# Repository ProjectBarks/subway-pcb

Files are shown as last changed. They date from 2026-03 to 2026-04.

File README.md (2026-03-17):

# NYC Subway PCB

Real-time NYC subway train tracker on a custom PCB with 478 WS2812B LEDs forming the subway map.

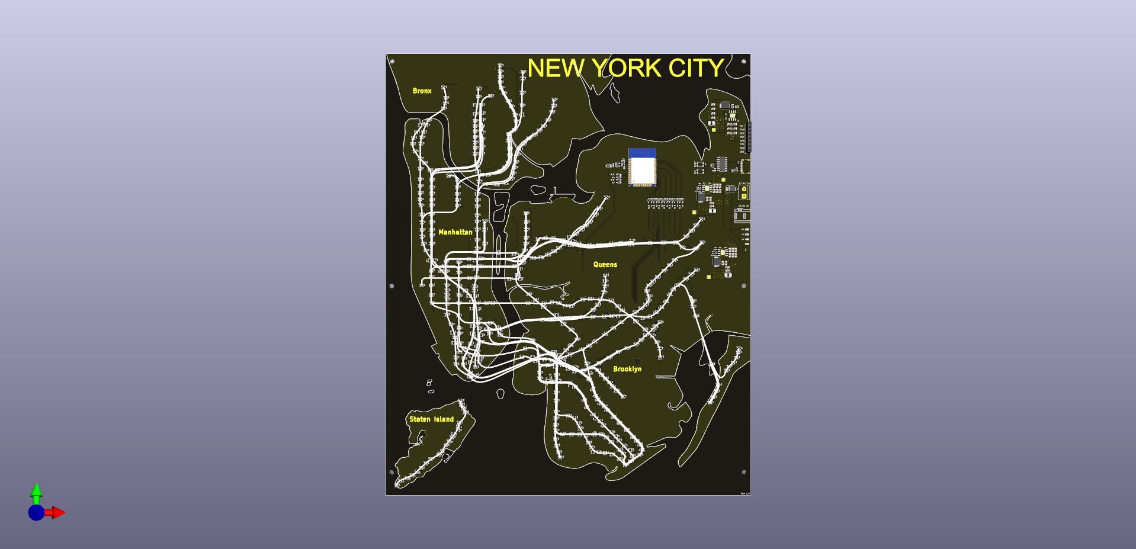
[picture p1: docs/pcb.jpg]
PCB Board


A Go server polls MTA's GTFS real-time feeds, renders train positions as pixel data, and streams it to an ESP32 over WiFi. Each LED lights up with the subway line's color when a train is at that station.

## Architecture

```
MTA GTFS-RT (9 feeds) → Go Server → protobuf → ESP32 → 478 LEDs
                              ↓
                     Web visualizer (:8080)
```

- **Server** polls MTA every 15s, maps trains to LED positions, serves pre-rendered pixel frames via protobuf
- **ESP32** connects to WiFi, fetches pixel data every second, drives 9 LED strips
- **Web UI** shows the same data overlaid on the PCB silkscreen (KiCad SVG)

## Quick Start

```bash
# Start the server (polls live MTA data, serves web UI + pixel API)
make server

# Flash production firmware to ESP32
make fw-flash

# Open web visualizer
open http://localhost:8080
```

## Project Structure

```
server/                    Go server
  cmd/subway-server/         Entry point
  internal/mta/              MTA feed polling + aggregation
  internal/api/              HTTP API + pixel rendering
  static/                    Web UI (board.js, app.js, leds.json, board.svg)
  led_map.json               Station → LED position mapping

firmware/                  ESP32 production firmware (PlatformIO + ESP-IDF)
  src/                       main.c, led_driver, subway_client
  proto/                     nanopb protobuf (PixelFrame)
  components/                External deps (esp_ghota, esp32-wifi-manager, led_strip)

proto/                     Shared protobuf schema (subway.proto)

pcb/                       KiCad hardware design files

tools/
  debug-firmware/            Arduino firmware for serial LED control
  led-debugger-ui/           Click-to-light web debugger (Python)
  led-mapping-ui/            LED position mapping tool (Python/Tkinter)
  serial-logger/             Resilient serial logger with auto-reconnect
```

## Make Targets

```
make help          Show all targets
make server        Build and start Go server
make fw-flash      Build and flash production firmware
make dbg-flash     Flash debug firmware (serial LED control)
make monitor       Start serial logger
make debugger      Start LED debugger web UI
make clean         Clean all build artifacts
```

## Hardware

- ESP32-WROOM-32 with CH340C USB-serial
- 478 WS2812B LEDs across 9 strips (GPIO 16-23, 25, 26)
- 12V barrel jack / battery terminal for LED power
- SN74LV1T34DBV level shifters (3.3V → 5V)

## Data Flow

1. Server fetches VehiclePosition from 9 MTA GTFS-RT feeds
2. Filters to STOPPED_AT trains only (actually at a station)
3. Maps station IDs to LED positions via `led_map.json`
4. Renders 478 RGB pixels with route-appropriate colors
5. Wraps in PixelFrame protobuf, serves at `GET /api/v1/pixels`
6. ESP32 polls every second, writes pixels directly to LED strips

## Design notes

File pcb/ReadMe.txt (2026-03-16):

Hello

Here are the projects files

The kicad project files contains the source files of your designs. you have to use Kicad software to open those files

gerber files are for manufacture the pcb.
pick and place files are useful if you use assembly service from the pcb manufacturer.

3d step file. this file is 3d model of you design. if this folder is empty then it means you have to ordered it.
The 3D design file is useful if you create a mechanical drawing with pcb.
For example if you design a enclouser. if you want to buy this let me know.

images and pdf folder contains images of pcb and schematic as pdf

BOM file is a excel file which contains the part list for your pcb

========================

For PCB manufacturing process I would like to recommend you PCBWay.com.
Here are some reasons I use their service.

1. Easy to use
2. They provide assembling service
3. They accept components from recognized stores such as mouser, digikey
4. They solder through hole components as well

I can guide you to place the order PCb using PCBWAY.COM

Additionally here is a referral link which will give you a discount
https://www.pcbway.com/setinvite.aspx?inviteid=325163

========================

here is ordering guide for PCBway.com, watch this video

https://drive.google.com/file/d/1q8oiihPp48wS0tmCgw_dWEVFPIduA3-2/view?usp=sharing

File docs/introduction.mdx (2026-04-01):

---
title: Introduction
description: Real-time NYC subway train tracker on a custom PCB with 478 WS2812B LEDs
---

NYC Subway PCB

# NYC Subway PCB

Real-time NYC subway train tracker on a custom PCB with 478 WS2812B LEDs forming the subway map.

A Go server polls MTA's GTFS real-time feeds, renders train positions as pixel data, and streams it to an ESP32 over WiFi. Each LED lights up with the subway line's color when a train is at that station.

## Architecture

```
MTA GTFS-RT (9 feeds) → Go Server → protobuf → ESP32 → 478 LEDs
                              ↓
                     Web visualizer (:8080)
```

- **Server** polls MTA every 15s, maps trains to LED positions, serves pre-rendered pixel frames via protobuf
- **ESP32** connects to WiFi, fetches pixel data every second, drives 9 LED strips
- **Web UI** shows the same data overlaid on the PCB silkscreen

## Quick Start

```bash
# Start the server (polls live MTA data, serves web UI + pixel API)
make backend/start

# Flash production firmware to ESP32
make firmware/flash

# Open web visualizer
open http://localhost:8080
```

## Hardware

- ESP32-WROOM-32 with CH340C USB-serial
- 478 WS2812B LEDs across 9 strips
- 12V barrel jack / battery terminal for LED power
- SN74LV1T34DBV level shifters (3.3V → 5V)

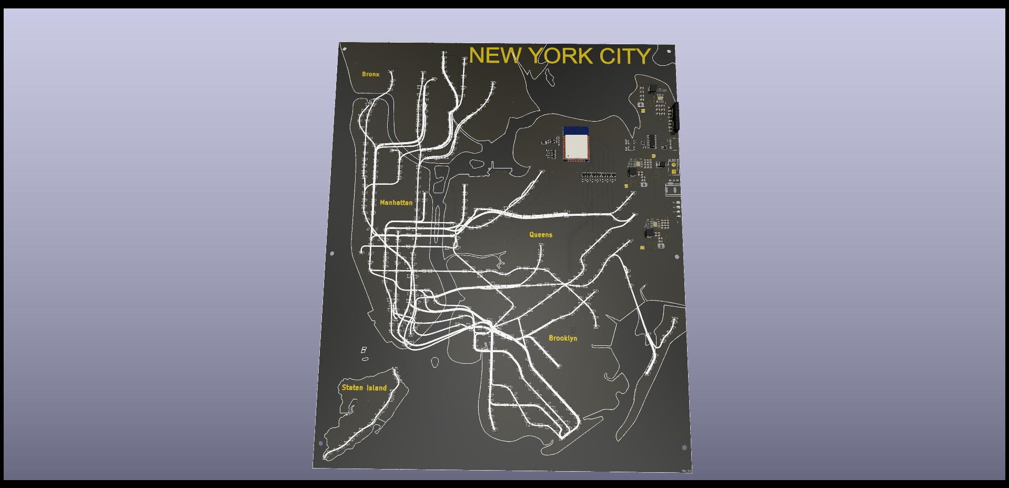
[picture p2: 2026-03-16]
pcb/images and pdf/design.jpg

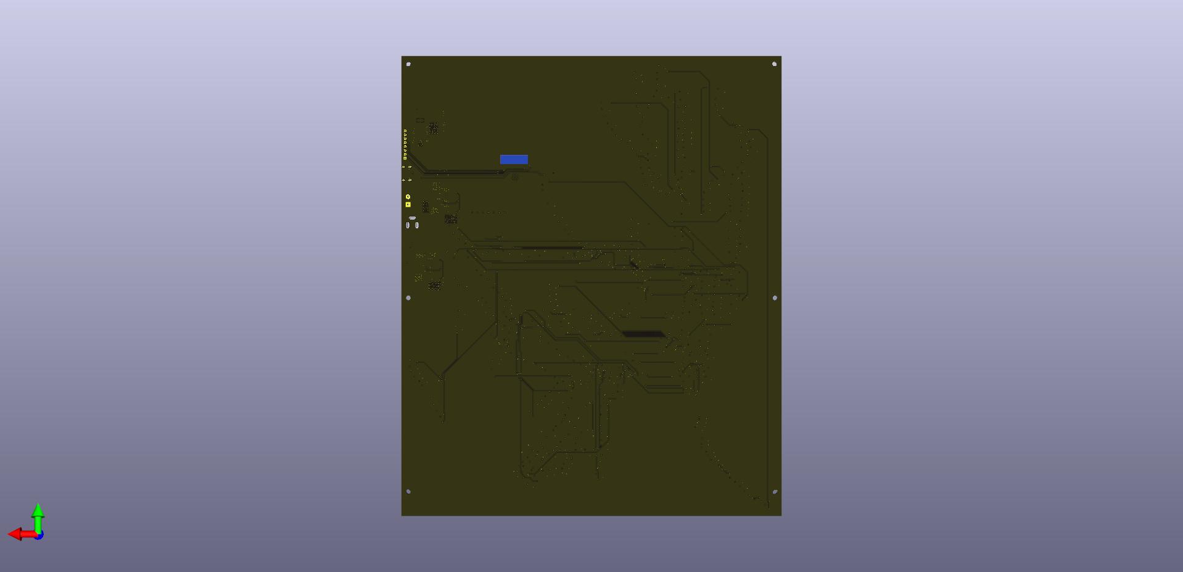
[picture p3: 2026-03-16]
pcb/images and pdf/bootm.jpg

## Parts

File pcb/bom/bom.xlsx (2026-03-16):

Designator | Comment | Footprint | JLCPCB Part # | MPN | Qty
C1 | 10uF | Capacitor_SMD:C_0603_1608Metric | C344022 | GRM188R61E106KA73D | 1
C2 | 0.1uF | Capacitor_SMD:C_0402_1005Metric | C77020 | GRM155R71H104KE14D | 1
C3 | 0.1uF | Capacitor_SMD:C_0402_1005Metric | C77020 | GRM155R71H104KE14D | 1
C4 | 10uF | Capacitor_SMD:C_0603_1608Metric | C344022 | GRM188R61E106KA73D | 1
C5 | 1uF | Capacitor_SMD:C_0603_1608Metric | C3011671 | GRT188R61H105ME13D | 1
C6 | 10uF | Capacitor_SMD:C_0603_1608Metric | C344022 | GRM188R61E106KA73D | 1
C7 | 10uF | Capacitor_SMD:C_0603_1608Metric | C344022 | GRM188R61E106KA73D | 1
C8 | 100u | CAPPM3528X210N | C597710 | TPSB107K006R0250 | 1
C9 | 10u 35v | Capacitor_SMD:C_0805_2012Metric | C361063 | GRM21BR6YA106ME43L | 1
C10 | 10u 35v | Capacitor_SMD:C_0805_2012Metric | C361063 | GRM21BR6YA106ME43L | 1
C11 | 10u 35v | Capacitor_SMD:C_0805_2012Metric | C361063 | GRM21BR6YA106ME43L | 1
C12 | 10u 35v | Capacitor_SMD:C_0805_2012Metric | C361063 | GRM21BR6YA106ME43L | 1
C13 | 0.1uF | Capacitor_SMD:C_0402_1005Metric | C77020 | GRM155R71H104KE14D | 1
C14 | nf | Capacitor_SMD:C_0402_1005Metric | dnp | dnp | 1
C15 | 10u 35v | Capacitor_SMD:C_0805_2012Metric | C361063 | GRM21BR6YA106ME43L | 1
C16 | 10u 35v | Capacitor_SMD:C_0805_2012Metric | C361063 | GRM21BR6YA106ME43L | 1
C17 | 10u 35v | Capacitor_SMD:C_0805_2012Metric | C361063 | GRM21BR6YA106ME43L | 1
C18 | 10u 35v | Capacitor_SMD:C_0805_2012Metric | C361063 | GRM21BR6YA106ME43L | 1
C19 | 10u 35v | Capacitor_SMD:C_0805_2012Metric | C361063 | GRM21BR6YA106ME43L | 1
C20 | 10u 35v | Capacitor_SMD:C_0805_2012Metric | C361063 | GRM21BR6YA106ME43L | 1
C21 | 0.1uF | Capacitor_SMD:C_0402_1005Metric | C77020 | GRM155R71H104KE14D | 1
C22 | nf | Capacitor_SMD:C_0402_1005Metric | dnp | dnp | 1
C23 | 1.2nF | Capacitor_SMD:C_0402_1005Metric | C295919 | 0402B122J500CT | 1
C24 | 100u | CAPPM3528X210N | C597710 | TPSB107K006R0250 | 1
C25 | 10u 35v | Capacitor_SMD:C_0805_2012Metric | C361063 | GRM21BR6YA106ME43L | 1
C26 | 10u 35v | Capacitor_SMD:C_0805_2012Metric | C361063 | GRM21BR6YA106ME43L | 1
C27 | 10u 35v | Capacitor_SMD:C_0805_2012Metric | C361063 | GRM21BR6YA106ME43L | 1
C28 | 10u 35v | Capacitor_SMD:C_0805_2012Metric | C361063 | GRM21BR6YA106ME43L | 1
C29 | 0.1uF | Capacitor_SMD:C_0402_1005Metric | C77020 | GRM155R71H104KE14D | 1
C30 | nf | Capacitor_SMD:C_0402_1005Metric | dnp | dnp | 1
C31 | 10u 35v | Capacitor_SMD:C_0805_2012Metric | C361063 | GRM21BR6YA106ME43L | 1
C32 | 10u 35v | Capacitor_SMD:C_0805_2012Metric | C361063 | GRM21BR6YA106ME43L | 1
C33 | 10u 35v | Capacitor_SMD:C_0805_2012Metric | C361063 | GRM21BR6YA106ME43L | 1
C34 | 10u 35v | Capacitor_SMD:C_0805_2012Metric | C361063 | GRM21BR6YA106ME43L | 1
C35 | 10u 35v | Capacitor_SMD:C_0805_2012Metric | C361063 | GRM21BR6YA106ME43L | 1
C36 | 10u 35v | Capacitor_SMD:C_0805_2012Metric | C361063 | GRM21BR6YA106ME43L | 1
C37 | 0.1uF | Capacitor_SMD:C_0402_1005Metric | C77020 | GRM155R71H104KE14D | 1
C38 | nf | Capacitor_SMD:C_0402_1005Metric | dnp | dnp | 1
C39 | 1.2nF | Capacitor_SMD:C_0402_1005Metric | C295919 | 0402B122J500CT | 1
C40 | 100u | CAPPM3528X210N | C597710 | TPSB107K006R0250 | 1
C41 | 10u 35v | Capacitor_SMD:C_0805_2012Metric | C361063 | GRM21BR6YA106ME43L | 1
C42 | 10u 35v | Capacitor_SMD:C_0805_2012Metric | C361063 | GRM21BR6YA106ME43L | 1
C43 | 10u 35v | Capacitor_SMD:C_0805_2012Metric | C361063 | GRM21BR6YA106ME43L | 1
C44 | 10u 35v | Capacitor_SMD:C_0805_2012Metric | C361063 | GRM21BR6YA106ME43L | 1
C45 | 0.1uF | Capacitor_SMD:C_0402_1005Metric | C77020 | GRM155R71H104KE14D | 1
C46 | nf | Capacitor_SMD:C_0402_1005Metric | dnp | dnp | 1
C47 | 10u 35v | Capacitor_SMD:C_0805_2012Metric | C361063 | GRM21BR6YA106ME43L | 1
C48 | 10u 35v | Capacitor_SMD:C_0805_2012Metric | C361063 | GRM21BR6YA106ME43L | 1
C49 | 10u 35v | Capacitor_SMD:C_0805_2012Metric | C361063 | GRM21BR6YA106ME43L | 1
C50 | 10u 35v | Capacitor_SMD:C_0805_2012Metric | C361063 | GRM21BR6YA106ME43L | 1
C51 | 10u 35v | Capacitor_SMD:C_0805_2012Metric | C361063 | GRM21BR6YA106ME43L | 1
C52 | 10u 35v | Capacitor_SMD:C_0805_2012Metric | C361063 | GRM21BR6YA106ME43L | 1
C53 | 0.1uF | Capacitor_SMD:C_0402_1005Metric | C77020 | GRM155R71H104KE14D | 1
C54 | nf | Capacitor_SMD:C_0402_1005Metric | dnp | dnp | 1
C55 | 1.2nF | Capacitor_SMD:C_0402_1005Metric | C295919 | 0402B122J500CT | 1
C56 | 0.1uF | Capacitor_SMD:C_0402_1005Metric | C77020 | GRM155R71H104KE14D | 1
C57 | 0.1uF | Capacitor_SMD:C_0402_1005Metric | C77020 | GRM155R71H104KE14D | 1
C58 | 0.1uF | Capacitor_SMD:C_0402_1005Metric | C77020 | GRM155R71H104KE14D | 1
C59 | 0.1uF | Capacitor_SMD:C_0402_1005Metric | C77020 | GRM155R71H104KE14D | 1
C60 | 0.1uF | Capacitor_SMD:C_0402_1005Metric | C77020 | GRM155R71H104KE14D | 1
C61 | 0.1uF | Capacitor_SMD:C_0402_1005Metric | C77020 | GRM155R71H104KE14D | 1
C62 | 0.1uF | Capacitor_SMD:C_0402_1005Metric | C77020 | GRM155R71H104KE14D | 1
C63 | 0.1uF | Capacitor_SMD:C_0402_1005Metric | C77020 | GRM155R71H104KE14D | 1
C64 | 0.1uF | Capacitor_SMD:C_0402_1005Metric | C77020 | GRM155R71H104KE14D | 1
C65 | 0.1uF | Capacitor_SMD:C_0402_1005Metric | C77020 | GRM155R71H104KE14D | 1
C66 | 0.1uF | Capacitor_SMD:C_0402_1005Metric | C77020 | GRM155R71H104KE14D | 1
C67 | 0.1uF | Capacitor_SMD:C_0402_1005Metric | C77020 | GRM155R71H104KE14D | 1
C68 | 0.1uF | Capacitor_SMD:C_0402_1005Metric | C77020 | GRM155R71H104KE14D | 1
C69 | 0.1uF | Capacitor_SMD:C_0402_1005Metric | C77020 | GRM155R71H104KE14D | 1
C70 | 0.1uF | Capacitor_SMD:C_0402_1005Metric | C77020 | GRM155R71H104KE14D | 1
C71 | 0.1uF | Capacitor_SMD:C_0402_1005Metric | C77020 | GRM155R71H104KE14D | 1
C72 | 0.1uF | Capacitor_SMD:C_0402_1005Metric | C77020 | GRM155R71H104KE14D | 1
C73 | 0.1uF | Capacitor_SMD:C_0402_1005Metric | C77020 | GRM155R71H104KE14D | 1
C74 | 0.1uF | Capacitor_SMD:C_0402_1005Metric | C77020 | GRM155R71H104KE14D | 1
C75 | 0.1uF | Capacitor_SMD:C_0402_1005Metric | C77020 | GRM155R71H104KE14D | 1
C76 | 0.1uF | Capacitor_SMD:C_0402_1005Metric | C77020 | GRM155R71H104KE14D | 1
C77 | 0.1uF | Capacitor_SMD:C_0402_1005Metric | C77020 | GRM155R71H104KE14D | 1
C78 | 0.1uF | Capacitor_SMD:C_0402_1005Metric | C77020 | GRM155R71H104KE14D | 1
C79 | 0.1uF | Capacitor_SMD:C_0402_1005Metric | C77020 | GRM155R71H104KE14D | 1
C80 | 0.1uF | Capacitor_SMD:C_0402_1005Metric | C77020 | GRM155R71H104KE14D | 1
C81 | 0.1uF | Capacitor_SMD:C_0402_1005Metric | C77020 | GRM155R71H104KE14D | 1
C82 | 0.1uF | Capacitor_SMD:C_0402_1005Metric | C77020 | GRM155R71H104KE14D | 1
C83 | 0.1uF | Capacitor_SMD:C_0402_1005Metric | C77020 | GRM155R71H104KE14D | 1
C84 | 0.1uF | Capacitor_SMD:C_0402_1005Metric | C77020 | GRM155R71H104KE14D | 1
C85 | 0.1uF | Capacitor_SMD:C_0402_1005Metric | C77020 | GRM155R71H104KE14D | 1
C86 | 0.1uF | Capacitor_SMD:C_0402_1005Metric | C77020 | GRM155R71H104KE14D | 1
C87 | 0.1uF | Capacitor_SMD:C_0402_1005Metric | C77020 | GRM155R71H104KE14D | 1
C88 | 0.1uF | Capacitor_SMD:C_0402_1005Metric | C77020 | GRM155R71H104KE14D | 1
C89 | 0.1uF | Capacitor_SMD:C_0402_1005Metric | C77020 | GRM155R71H104KE14D | 1
C90 | 0.1uF | Capacitor_SMD:C_0402_1005Metric | C77020 | GRM155R71H104KE14D | 1
C91 | 0.1uF | Capacitor_SMD:C_0402_1005Metric | C77020 | GRM155R71H104KE14D | 1
C92 | 0.1uF | Capacitor_SMD:C_0402_1005Metric | C77020 | GRM155R71H104KE14D | 1
C93 | 0.1uF | Capacitor_SMD:C_0402_1005Metric | C77020 | GRM155R71H104KE14D | 1
C94 | 0.1uF | Capacitor_SMD:C_0402_1005Metric | C77020 | GRM155R71H104KE14D | 1
C95 | 0.1uF | Capacitor_SMD:C_0402_1005Metric | C77020 | GRM155R71H104KE14D | 1
C96 | 0.1uF | Capacitor_SMD:C_0402_1005Metric | C77020 | GRM155R71H104KE14D | 1
C97 | 0.1uF | Capacitor_SMD:C_0402_1005Metric | C77020 | GRM155R71H104KE14D | 1
C98 | 0.1uF | Capacitor_SMD:C_0402_1005Metric | C77020 | GRM155R71H104KE14D | 1
C99 | 0.1uF | Capacitor_SMD:C_0402_1005Metric | C77020 | GRM155R71H104KE14D | 1
C100 | 0.1uF | Capacitor_SMD:C_0402_1005Metric | C77020 | GRM155R71H104KE14D | 1
C101 | 0.1uF | Capacitor_SMD:C_0402_1005Metric | C77020 | GRM155R71H104KE14D | 1
C102 | 0.1uF | Capacitor_SMD:C_0402_1005Metric | C77020 | GRM155R71H104KE14D | 1
C103 | 0.1uF | Capacitor_SMD:C_0402_1005Metric | C77020 | GRM155R71H104KE14D | 1
C104 | 0.1uF | Capacitor_SMD:C_0402_1005Metric | C77020 | GRM155R71H104KE14D | 1
C105 | 0.1uF | Capacitor_SMD:C_0402_1005Metric | C77020 | GRM155R71H104KE14D | 1
C106 | 0.1uF | Capacitor_SMD:C_0402_1005Metric | C77020 | GRM155R71H104KE14D | 1
C107 | 0.1uF | Capacitor_SMD:C_0402_1005Metric | C77020 | GRM155R71H104KE14D | 1
C108 | 0.1uF | Capacitor_SMD:C_0402_1005Metric | C77020 | GRM155R71H104KE14D | 1
C109 | 0.1uF | Capacitor_SMD:C_0402_1005Metric | C77020 | GRM155R71H104KE14D | 1
C110 | 0.1uF | Capacitor_SMD:C_0402_1005Metric | C77020 | GRM155R71H104KE14D | 1
C111 | 0.1uF | Capacitor_SMD:C_0402_1005Metric | C77020 | GRM155R71H104KE14D | 1
C112 | 0.1uF | Capacitor_SMD:C_0402_1005Metric | C77020 | GRM155R71H104KE14D | 1
C113 | 0.1uF | Capacitor_SMD:C_0402_1005Metric | C77020 | GRM155R71H104KE14D | 1
C114 | 0.1uF | Capacitor_SMD:C_0402_1005Metric | C77020 | GRM155R71H104KE14D | 1
C115 | 0.1uF | Capacitor_SMD:C_0402_1005Metric | C77020 | GRM155R71H104KE14D | 1
C116 | 0.1uF | Capacitor_SMD:C_0402_1005Metric | C77020 | GRM155R71H104KE14D | 1
C117 | 0.1uF | Capacitor_SMD:C_0402_1005Metric | C77020 | GRM155R71H104KE14D | 1
C118 | 0.1uF | Capacitor_SMD:C_0402_1005Metric | C77020 | GRM155R71H104KE14D | 1
C119 | 0.1uF | Capacitor_SMD:C_0402_1005Metric | C77020 | GRM155R71H104KE14D | 1
C120 | 0.1uF | Capacitor_SMD:C_0402_1005Metric | C77020 | GRM155R71H104KE14D | 1
C121 | 0.1uF | Capacitor_SMD:C_0402_1005Metric | C77020 | GRM155R71H104KE14D | 1
C122 | 0.1uF | Capacitor_SMD:C_0402_1005Metric | C77020 | GRM155R71H104KE14D | 1
C123 | 0.1uF | Capacitor_SMD:C_0402_1005Metric | C77020 | GRM155R71H104KE14D | 1
C124 | 0.1uF | Capacitor_SMD:C_0402_1005Metric | C77020 | GRM155R71H104KE14D | 1
C125 | 0.1uF | Capacitor_SMD:C_0402_1005Metric | C77020 | GRM155R71H104KE14D | 1
C126 | 0.1uF | Capacitor_SMD:C_0402_1005Metric | C77020 | GRM155R71H104KE14D | 1
C127 | 0.1uF | Capacitor_SMD:C_0402_1005Metric | C77020 | GRM155R71H104KE14D | 1
C128 | 0.1uF | Capacitor_SMD:C_0402_1005Metric | C77020 | GRM155R71H104KE14D | 1
C129 | 0.1uF | Capacitor_SMD:C_0402_1005Metric | C77020 | GRM155R71H104KE14D | 1
C130 | 0.1uF | Capacitor_SMD:C_0402_1005Metric | C77020 | GRM155R71H104KE14D | 1
C131 | 0.1uF | Capacitor_SMD:C_0402_1005Metric | C77020 | GRM155R71H104KE14D | 1
C132 | 0.1uF | Capacitor_SMD:C_0402_1005Metric | C77020 | GRM155R71H104KE14D | 1
C133 | 0.1uF | Capacitor_SMD:C_0402_1005Metric | C77020 | GRM155R71H104KE14D | 1
C134 | 0.1uF | Capacitor_SMD:C_0402_1005Metric | C77020 | GRM155R71H104KE14D | 1
C135 | 0.1uF | Capacitor_SMD:C_0402_1005Metric | C77020 | GRM155R71H104KE14D | 1
C136 | 0.1uF | Capacitor_SMD:C_0402_1005Metric | C77020 | GRM155R71H104KE14D | 1
C137 | 0.1uF | Capacitor_SMD:C_0402_1005Metric | C77020 | GRM155R71H104KE14D | 1
C138 | 0.1uF | Capacitor_SMD:C_0402_1005Metric | C77020 | GRM155R71H104KE14D | 1
C139 | 0.1uF | Capacitor_SMD:C_0402_1005Metric | C77020 | GRM155R71H104KE14D | 1
C140 | 0.1uF | Capacitor_SMD:C_0402_1005Metric | C77020 | GRM155R71H104KE14D | 1
C141 | 0.1uF | Capacitor_SMD:C_0402_1005Metric | C77020 | GRM155R71H104KE14D | 1
C142 | 0.1uF | Capacitor_SMD:C_0402_1005Metric | C77020 | GRM155R71H104KE14D | 1
C143 | 0.1uF | Capacitor_SMD:C_0402_1005Metric | C77020 | GRM155R71H104KE14D | 1
C144 | 0.1uF | Capacitor_SMD:C_0402_1005Metric | C77020 | GRM155R71H104KE14D | 1
C145 | 0.1uF | Capacitor_SMD:C_0402_1005Metric | C77020 | GRM155R71H104KE14D | 1
C146 | 0.1uF | Capacitor_SMD:C_0402_1005Metric | C77020 | GRM155R71H104KE14D | 1
C147 | 0.1uF | Capacitor_SMD:C_0402_1005Metric | C77020 | GRM155R71H104KE14D | 1
C148 | 0.1uF | Capacitor_SMD:C_0402_1005Metric | C77020 | GRM155R71H104KE14D | 1
C149 | 0.1uF | Capacitor_SMD:C_0402_1005Metric | C77020 | GRM155R71H104KE14D | 1
C150 | 0.1uF | Capacitor_SMD:C_0402_1005Metric | C77020 | GRM155R71H104KE14D | 1
C151 | 0.1uF | Capacitor_SMD:C_0402_1005Metric | C77020 | GRM155R71H104KE14D | 1
C152 | 0.1uF | Capacitor_SMD:C_0402_1005Metric | C77020 | GRM155R71H104KE14D | 1
C153 | 0.1uF | Capacitor_SMD:C_0402_1005Metric | C77020 | GRM155R71H104KE14D | 1
C154 | 0.1uF | Capacitor_SMD:C_0402_1005Metric | C77020 | GRM155R71H104KE14D | 1
C155 | 0.1uF | Capacitor_SMD:C_0402_1005Metric | C77020 | GRM155R71H104KE14D | 1
C156 | 0.1uF | Capacitor_SMD:C_0402_1005Metric | C77020 | GRM155R71H104KE14D | 1
C157 | 0.1uF | Capacitor_SMD:C_0402_1005Metric | C77020 | GRM155R71H104KE14D | 1
C158 | 0.1uF | Capacitor_SMD:C_0402_1005Metric | C77020 | GRM155R71H104KE14D | 1
C159 | 0.1uF | Capacitor_SMD:C_0402_1005Metric | C77020 | GRM155R71H104KE14D | 1
C160 | 0.1uF | Capacitor_SMD:C_0402_1005Metric | C77020 | GRM155R71H104KE14D | 1
C161 | 0.1uF | Capacitor_SMD:C_0402_1005Metric | C77020 | GRM155R71H104KE14D | 1
C162 | 0.1uF | Capacitor_SMD:C_0402_1005Metric | C77020 | GRM155R71H104KE14D | 1
C163 | 0.1uF | Capacitor_SMD:C_0402_1005Metric | C77020 | GRM155R71H104KE14D | 1
C164 | 0.1uF | Capacitor_SMD:C_0402_1005Metric | C77020 | GRM155R71H104KE14D | 1
C165 | 0.1uF | Capacitor_SMD:C_0402_1005Metric | C77020 | GRM155R71H104KE14D | 1
C166 | 0.1uF | Capacitor_SMD:C_0402_1005Metric | C77020 | GRM155R71H104KE14D | 1
C167 | 0.1uF | Capacitor_SMD:C_0402_1005Metric | C77020 | GRM155R71H104KE14D | 1
C168 | 0.1uF | Capacitor_SMD:C_0402_1005Metric | C77020 | GRM155R71H104KE14D | 1
C169 | 0.1uF | Capacitor_SMD:C_0402_1005Metric | C77020 | GRM155R71H104KE14D | 1
C170 | 0.1uF | Capacitor_SMD:C_0402_1005Metric | C77020 | GRM155R71H104KE14D | 1
C171 | 0.1uF | Capacitor_SMD:C_0402_1005Metric | C77020 | GRM155R71H104KE14D | 1
C172 | 0.1uF | Capacitor_SMD:C_0402_1005Metric | C77020 | GRM155R71H104KE14D | 1
C173 | 0.1uF | Capacitor_SMD:C_0402_1005Metric | C77020 | GRM155R71H104KE14D | 1
C174 | 0.1uF | Capacitor_SMD:C_0402_1005Metric | C77020 | GRM155R71H104KE14D | 1
C175 | 0.1uF | Capacitor_SMD:C_0402_1005Metric | C77020 | GRM155R71H104KE14D | 1
C176 | 0.1uF | Capacitor_SMD:C_0402_1005Metric | C77020 | GRM155R71H104KE14D | 1
C177 | 0.1uF | Capacitor_SMD:C_0402_1005Metric | C77020 | GRM155R71H104KE14D | 1
C178 | 0.1uF | Capacitor_SMD:C_0402_1005Metric | C77020 | GRM155R71H104KE14D | 1
C179 | 0.1uF | Capacitor_SMD:C_0402_1005Metric | C77020 | GRM155R71H104KE14D | 1
C180 | 0.1uF | Capacitor_SMD:C_0402_1005Metric | C77020 | GRM155R71H104KE14D | 1
C181 | 0.1uF | Capacitor_SMD:C_0402_1005Metric | C77020 | GRM155R71H104KE14D | 1
C182 | 0.1uF | Capacitor_SMD:C_0402_1005Metric | C77020 | GRM155R71H104KE14D | 1
C183 | 0.1uF | Capacitor_SMD:C_0402_1005Metric | C77020 | GRM155R71H104KE14D | 1
C184 | 0.1uF | Capacitor_SMD:C_0402_1005Metric | C77020 | GRM155R71H104KE14D | 1
C185 | 0.1uF | Capacitor_SMD:C_0402_1005Metric | C77020 | GRM155R71H104KE14D | 1
C186 | 0.1uF | Capacitor_SMD:C_0402_1005Metric | C77020 | GRM155R71H104KE14D | 1
C187 | 0.1uF | Capacitor_SMD:C_0402_1005Metric | C77020 | GRM155R71H104KE14D | 1
C188 | 0.1uF | Capacitor_SMD:C_0402_1005Metric | C77020 | GRM155R71H104KE14D | 1
C189 | 0.1uF | Capacitor_SMD:C_0402_1005Metric | C77020 | GRM155R71H104KE14D | 1
C190 | 0.1uF | Capacitor_SMD:C_0402_1005Metric | C77020 | GRM155R71H104KE14D | 1
C191 | 0.1uF | Capacitor_SMD:C_0402_1005Metric | C77020 | GRM155R71H104KE14D | 1
C192 | 0.1uF | Capacitor_SMD:C_0402_1005Metric | C77020 | GRM155R71H104KE14D | 1
C193 | 0.1uF | Capacitor_SMD:C_0402_1005Metric | C77020 | GRM155R71H104KE14D | 1
C194 | 0.1uF | Capacitor_SMD:C_0402_1005Metric | C77020 | GRM155R71H104KE14D | 1
C195 | 0.1uF | Capacitor_SMD:C_0402_1005Metric | C77020 | GRM155R71H104KE14D | 1
C196 | 0.1uF | Capacitor_SMD:C_0402_1005Metric | C77020 | GRM155R71H104KE14D | 1
C197 | 0.1uF | Capacitor_SMD:C_0402_1005Metric | C77020 | GRM155R71H104KE14D | 1
C198 | 0.1uF | Capacitor_SMD:C_0402_1005Metric | C77020 | GRM155R71H104KE14D | 1
C199 | 0.1uF | Capacitor_SMD:C_0402_1005Metric | C77020 | GRM155R71H104KE14D | 1
C200 | 0.1uF | Capacitor_SMD:C_0402_1005Metric | C77020 | GRM155R71H104KE14D | 1
C201 | 0.1uF | Capacitor_SMD:C_0402_1005Metric | C77020 | GRM155R71H104KE14D | 1
C202 | 0.1uF | Capacitor_SMD:C_0402_1005Metric | C77020 | GRM155R71H104KE14D | 1
C203 | 0.1uF | Capacitor_SMD:C_0402_1005Metric | C77020 | GRM155R71H104KE14D | 1
C204 | 0.1uF | Capacitor_SMD:C_0402_1005Metric | C77020 | GRM155R71H104KE14D | 1
C205 | 0.1uF | Capacitor_SMD:C_0402_1005Metric | C77020 | GRM155R71H104KE14D | 1
C206 | 0.1uF | Capacitor_SMD:C_0402_1005Metric | C77020 | GRM155R71H104KE14D | 1
C207 | 0.1uF | Capacitor_SMD:C_0402_1005Metric | C77020 | GRM155R71H104KE14D | 1
C208 | 0.1uF | Capacitor_SMD:C_0402_1005Metric | C77020 | GRM155R71H104KE14D | 1
C209 | 0.1uF | Capacitor_SMD:C_0402_1005Metric | C77020 | GRM155R71H104KE14D | 1
C210 | 0.1uF | Capacitor_SMD:C_0402_1005Metric | C77020 | GRM155R71H104KE14D | 1
C211 | 0.1uF | Capacitor_SMD:C_0402_1005Metric | C77020 | GRM155R71H104KE14D | 1
C212 | 0.1uF | Capacitor_SMD:C_0402_1005Metric | C77020 | GRM155R71H104KE14D | 1
C213 | 0.1uF | Capacitor_SMD:C_0402_1005Metric | C77020 | GRM155R71H104KE14D | 1
C214 | 0.1uF | Capacitor_SMD:C_0402_1005Metric | C77020 | GRM155R71H104KE14D | 1
C215 | 0.1uF | Capacitor_SMD:C_0402_1005Metric | C77020 | GRM155R71H104KE14D | 1
C216 | 0.1uF | Capacitor_SMD:C_0402_1005Metric | C77020 | GRM155R71H104KE14D | 1
C217 | 0.1uF | Capacitor_SMD:C_0402_1005Metric | C77020 | GRM155R71H104KE14D | 1
C218 | 0.1uF | Capacitor_SMD:C_0402_1005Metric | C77020 | GRM155R71H104KE14D | 1
C219 | 0.1uF | Capacitor_SMD:C_0402_1005Metric | C77020 | GRM155R71H104KE14D | 1
C220 | 0.1uF | Capacitor_SMD:C_0402_1005Metric | C77020 | GRM155R71H104KE14D | 1
C221 | 0.1uF | Capacitor_SMD:C_0402_1005Metric | C77020 | GRM155R71H104KE14D | 1
C222 | 0.1uF | Capacitor_SMD:C_0402_1005Metric | C77020 | GRM155R71H104KE14D | 1
C223 | 0.1uF | Capacitor_SMD:C_0402_1005Metric | C77020 | GRM155R71H104KE14D | 1
C224 | 0.1uF | Capacitor_SMD:C_0402_1005Metric | C77020 | GRM155R71H104KE14D | 1
C225 | 0.1uF | Capacitor_SMD:C_0402_1005Metric | C77020 | GRM155R71H104KE14D | 1
C226 | 0.1uF | Capacitor_SMD:C_0402_1005Metric | C77020 | GRM155R71H104KE14D | 1
C227 | 0.1uF | Capacitor_SMD:C_0402_1005Metric | C77020 | GRM155R71H104KE14D | 1
C228 | 0.1uF | Capacitor_SMD:C_0402_1005Metric | C77020 | GRM155R71H104KE14D | 1
C229 | 0.1uF | Capacitor_SMD:C_0402_1005Metric | C77020 | GRM155R71H104KE14D | 1
C230 | 0.1uF | Capacitor_SMD:C_0402_1005Metric | C77020 | GRM155R71H104KE14D | 1
C231 | 0.1uF | Capacitor_SMD:C_0402_1005Metric | C77020 | GRM155R71H104KE14D | 1
C232 | 0.1uF | Capacitor_SMD:C_0402_1005Metric | C77020 | GRM155R71H104KE14D | 1
C233 | 0.1uF | Capacitor_SMD:C_0402_1005Metric | C77020 | GRM155R71H104KE14D | 1
C234 | 0.1uF | Capacitor_SMD:C_0402_1005Metric | C77020 | GRM155R71H104KE14D | 1
C235 | 0.1uF | Capacitor_SMD:C_0402_1005Metric | C77020 | GRM155R71H104KE14D | 1
C236 | 0.1uF | Capacitor_SMD:C_0402_1005Metric | C77020 | GRM155R71H104KE14D | 1
C237 | 0.1uF | Capacitor_SMD:C_0402_1005Metric | C77020 | GRM155R71H104KE14D | 1
C238 | 0.1uF | Capacitor_SMD:C_0402_1005Metric | C77020 | GRM155R71H104KE14D | 1
C239 | 0.1uF | Capacitor_SMD:C_0402_1005Metric | C77020 | GRM155R71H104KE14D | 1
C240 | 0.1uF | Capacitor_SMD:C_0402_1005Metric | C77020 | GRM155R71H104KE14D | 1
C241 | 0.1uF | Capacitor_SMD:C_0402_1005Metric | C77020 | GRM155R71H104KE14D | 1
C242 | 0.1uF | Capacitor_SMD:C_0402_1005Metric | C77020 | GRM155R71H104KE14D | 1
C243 | 0.1uF | Capacitor_SMD:C_0402_1005Metric | C77020 | GRM155R71H104KE14D | 1
C244 | 0.1uF | Capacitor_SMD:C_0402_1005Metric | C77020 | GRM155R71H104KE14D | 1
C245 | 0.1uF | Capacitor_SMD:C_0402_1005Metric | C77020 | GRM155R71H104KE14D | 1
C246 | 0.1uF | Capacitor_SMD:C_0402_1005Metric | C77020 | GRM155R71H104KE14D | 1
C247 | 0.1uF | Capacitor_SMD:C_0402_1005Metric | C77020 | GRM155R71H104KE14D | 1
C248 | 0.1uF | Capacitor_SMD:C_0402_1005Metric | C77020 | GRM155R71H104KE14D | 1
C249 | 0.1uF | Capacitor_SMD:C_0402_1005Metric | C77020 | GRM155R71H104KE14D | 1
C250 | 0.1uF | Capacitor_SMD:C_0402_1005Metric | C77020 | GRM155R71H104KE14D | 1
C251 | 0.1uF | Capacitor_SMD:C_0402_1005Metric | C77020 | GRM155R71H104KE14D | 1
C252 | 0.1uF | Capacitor_SMD:C_0402_1005Metric | C77020 | GRM155R71H104KE14D | 1
C253 | 0.1uF | Capacitor_SMD:C_0402_1005Metric | C77020 | GRM155R71H104KE14D | 1
C254 | 0.1uF | Capacitor_SMD:C_0402_1005Metric | C77020 | GRM155R71H104KE14D | 1
C255 | 0.1uF | Capacitor_SMD:C_0402_1005Metric | C77020 | GRM155R71H104KE14D | 1
C256 | 0.1uF | Capacitor_SMD:C_0402_1005Metric | C77020 | GRM155R71H104KE14D | 1
C257 | 0.1uF | Capacitor_SMD:C_0402_1005Metric | C77020 | GRM155R71H104KE14D | 1
C258 | 0.1uF | Capacitor_SMD:C_0402_1005Metric | C77020 | GRM155R71H104KE14D | 1
C259 | 0.1uF | Capacitor_SMD:C_0402_1005Metric | C77020 | GRM155R71H104KE14D | 1
C260 | 0.1uF | Capacitor_SMD:C_0402_1005Metric | C77020 | GRM155R71H104KE14D | 1
C261 | 0.1uF | Capacitor_SMD:C_0402_1005Metric | C77020 | GRM155R71H104KE14D | 1
C262 | 0.1uF | Capacitor_SMD:C_0402_1005Metric | C77020 | GRM155R71H104KE14D | 1
C263 | 0.1uF | Capacitor_SMD:C_0402_1005Metric | C77020 | GRM155R71H104KE14D | 1
C264 | 0.1uF | Capacitor_SMD:C_0402_1005Metric | C77020 | GRM155R71H104KE14D | 1
C265 | 0.1uF | Capacitor_SMD:C_0402_1005Metric | C77020 | GRM155R71H104KE14D | 1
C266 | 0.1uF | Capacitor_SMD:C_0402_1005Metric | C77020 | GRM155R71H104KE14D | 1
C267 | 0.1uF | Capacitor_SMD:C_0402_1005Metric | C77020 | GRM155R71H104KE14D | 1
C268 | 0.1uF | Capacitor_SMD:C_0402_1005Metric | C77020 | GRM155R71H104KE14D | 1
C269 | 0.1uF | Capacitor_SMD:C_0402_1005Metric | C77020 | GRM155R71H104KE14D | 1
C270 | 0.1uF | Capacitor_SMD:C_0402_1005Metric | C77020 | GRM155R71H104KE14D | 1
C271 | 0.1uF | Capacitor_SMD:C_0402_1005Metric | C77020 | GRM155R71H104KE14D | 1
C272 | 0.1uF | Capacitor_SMD:C_0402_1005Metric | C77020 | GRM155R71H104KE14D | 1
C273 | 0.1uF | Capacitor_SMD:C_0402_1005Metric | C77020 | GRM155R71H104KE14D | 1
C274 | 0.1uF | Capacitor_SMD:C_0402_1005Metric | C77020 | GRM155R71H104KE14D | 1
C275 | 0.1uF | Capacitor_SMD:C_0402_1005Metric | C77020 | GRM155R71H104KE14D | 1
C276 | 0.1uF | Capacitor_SMD:C_0402_1005Metric | C77020 | GRM155R71H104KE14D | 1
C277 | 0.1uF | Capacitor_SMD:C_0402_1005Metric | C77020 | GRM155R71H104KE14D | 1
C278 | 0.1uF | Capacitor_SMD:C_0402_1005Metric | C77020 | GRM155R71H104KE14D | 1
C279 | 0.1uF | Capacitor_SMD:C_0402_1005Metric | C77020 | GRM155R71H104KE14D | 1
C280 | 0.1uF | Capacitor_SMD:C_0402_1005Metric | C77020 | GRM155R71H104KE14D | 1
C281 | 0.1uF | Capacitor_SMD:C_0402_1005Metric | C77020 | GRM155R71H104KE14D | 1
C282 | 0.1uF | Capacitor_SMD:C_0402_1005Metric | C77020 | GRM155R71H104KE14D | 1
C283 | 0.1uF | Capacitor_SMD:C_0402_1005Metric | C77020 | GRM155R71H104KE14D | 1
C284 | 0.1uF | Capacitor_SMD:C_0402_1005Metric | C77020 | GRM155R71H104KE14D | 1
C285 | 0.1uF | Capacitor_SMD:C_0402_1005Metric | C77020 | GRM155R71H104KE14D | 1
C286 | 0.1uF | Capacitor_SMD:C_0402_1005Metric | C77020 | GRM155R71H104KE14D | 1
C287 | 0.1uF | Capacitor_SMD:C_0402_1005Metric | C77020 | GRM155R71H104KE14D | 1
C288 | 0.1uF | Capacitor_SMD:C_0402_1005Metric | C77020 | GRM155R71H104KE14D | 1
C289 | 0.1uF | Capacitor_SMD:C_0402_1005Metric | C77020 | GRM155R71H104KE14D | 1
C290 | 0.1uF | Capacitor_SMD:C_0402_1005Metric | C77020 | GRM155R71H104KE14D | 1
C291 | 0.1uF | Capacitor_SMD:C_0402_1005Metric | C77020 | GRM155R71H104KE14D | 1
C292 | 0.1uF | Capacitor_SMD:C_0402_1005Metric | C77020 | GRM155R71H104KE14D | 1
C293 | 0.1uF | Capacitor_SMD:C_0402_1005Metric | C77020 | GRM155R71H104KE14D | 1
C294 | 0.1uF | Capacitor_SMD:C_0402_1005Metric | C77020 | GRM155R71H104KE14D | 1
C295 | 0.1uF | Capacitor_SMD:C_0402_1005Metric | C77020 | GRM155R71H104KE14D | 1
C296 | 0.1uF | Capacitor_SMD:C_0402_1005Metric | C77020 | GRM155R71H104KE14D | 1
C297 | 0.1uF | Capacitor_SMD:C_0402_1005Metric | C77020 | GRM155R71H104KE14D | 1
C298 | 0.1uF | Capacitor_SMD:C_0402_1005Metric | C77020 | GRM155R71H104KE14D | 1
C299 | 0.1uF | Capacitor_SMD:C_0402_1005Metric | C77020 | GRM155R71H104KE14D | 1
C300 | 0.1uF | Capacitor_SMD:C_0402_1005Metric | C77020 | GRM155R71H104KE14D | 1
C301 | 0.1uF | Capacitor_SMD:C_0402_1005Metric | C77020 | GRM155R71H104KE14D | 1
C302 | 0.1uF | Capacitor_SMD:C_0402_1005Metric | C77020 | GRM155R71H104KE14D | 1
C303 | 0.1uF | Capacitor_SMD:C_0402_1005Metric | C77020 | GRM155R71H104KE14D | 1
C304 | 0.1uF | Capacitor_SMD:C_0402_1005Metric | C77020 | GRM155R71H104KE14D | 1
C305 | 0.1uF | Capacitor_SMD:C_0402_1005Metric | C77020 | GRM155R71H104KE14D | 1
C306 | 0.1uF | Capacitor_SMD:C_0402_1005Metric | C77020 | GRM155R71H104KE14D | 1
C307 | 0.1uF | Capacitor_SMD:C_0402_1005Metric | C77020 | GRM155R71H104KE14D | 1
C308 | 0.1uF | Capacitor_SMD:C_0402_1005Metric | C77020 | GRM155R71H104KE14D | 1
C309 | 0.1uF | Capacitor_SMD:C_0402_1005Metric | C77020 | GRM155R71H104KE14D | 1
C310 | 0.1uF | Capacitor_SMD:C_0402_1005Metric | C77020 | GRM155R71H104KE14D | 1
C311 | 0.1uF | Capacitor_SMD:C_0402_1005Metric | C77020 | GRM155R71H104KE14D | 1
C312 | 0.1uF | Capacitor_SMD:C_0402_1005Metric | C77020 | GRM155R71H104KE14D | 1
C313 | 0.1uF | Capacitor_SMD:C_0402_1005Metric | C77020 | GRM155R71H104KE14D | 1
C314 | 0.1uF | Capacitor_SMD:C_0402_1005Metric | C77020 | GRM155R71H104KE14D | 1
C315 | 0.1uF | Capacitor_SMD:C_0402_1005Metric | C77020 | GRM155R71H104KE14D | 1
C316 | 0.1uF | Capacitor_SMD:C_0402_1005Metric | C77020 | GRM155R71H104KE14D | 1
C317 | 0.1uF | Capacitor_SMD:C_0402_1005Metric | C77020 | GRM155R71H104KE14D | 1
C318 | 0.1uF | Capacitor_SMD:C_0402_1005Metric | C77020 | GRM155R71H104KE14D | 1
C319 | 0.1uF | Capacitor_SMD:C_0402_1005Metric | C77020 | GRM155R71H104KE14D | 1
C320 | 0.1uF | Capacitor_SMD:C_0402_1005Metric | C77020 | GRM155R71H104KE14D | 1
C321 | 0.1uF | Capacitor_SMD:C_0402_1005Metric | C77020 | GRM155R71H104KE14D | 1
C322 | 0.1uF | Capacitor_SMD:C_0402_1005Metric | C77020 | GRM155R71H104KE14D | 1
C323 | 0.1uF | Capacitor_SMD:C_0402_1005Metric | C77020 | GRM155R71H104KE14D | 1
C324 | 0.1uF | Capacitor_SMD:C_0402_1005Metric | C77020 | GRM155R71H104KE14D | 1
C325 | 0.1uF | Capacitor_SMD:C_0402_1005Metric | C77020 | GRM155R71H104KE14D | 1
C326 | 0.1uF | Capacitor_SMD:C_0402_1005Metric | C77020 | GRM155R71H104KE14D | 1
C327 | 0.1uF | Capacitor_SMD:C_0402_1005Metric | C77020 | GRM155R71H104KE14D | 1
C328 | 0.1uF | Capacitor_SMD:C_0402_1005Metric | C77020 | GRM155R71H104KE14D | 1
C329 | 0.1uF | Capacitor_SMD:C_0402_1005Metric | C77020 | GRM155R71H104KE14D | 1
C330 | 0.1uF | Capacitor_SMD:C_0402_1005Metric | C77020 | GRM155R71H104KE14D | 1
C331 | 0.1uF | Capacitor_SMD:C_0402_1005Metric | C77020 | GRM155R71H104KE14D | 1
C332 | 0.1uF | Capacitor_SMD:C_0402_1005Metric | C77020 | GRM155R71H104KE14D | 1
C333 | 0.1uF | Capacitor_SMD:C_0402_1005Metric | C77020 | GRM155R71H104KE14D | 1
C334 | 0.1uF | Capacitor_SMD:C_0402_1005Metric | C77020 | GRM155R71H104KE14D | 1
C335 | 0.1uF | Capacitor_SMD:C_0402_1005Metric | C77020 | GRM155R71H104KE14D | 1
C336 | 0.1uF | Capacitor_SMD:C_0402_1005Metric | C77020 | GRM155R71H104KE14D | 1
C337 | 0.1uF | Capacitor_SMD:C_0402_1005Metric | C77020 | GRM155R71H104KE14D | 1
C338 | 0.1uF | Capacitor_SMD:C_0402_1005Metric | C77020 | GRM155R71H104KE14D | 1
C339 | 0.1uF | Capacitor_SMD:C_0402_1005Metric | C77020 | GRM155R71H104KE14D | 1
C340 | 0.1uF | Capacitor_SMD:C_0402_1005Metric | C77020 | GRM155R71H104KE14D | 1
C341 | 0.1uF | Capacitor_SMD:C_0402_1005Metric | C77020 | GRM155R71H104KE14D | 1
C342 | 0.1uF | Capacitor_SMD:C_0402_1005Metric | C77020 | GRM155R71H104KE14D | 1
C343 | 0.1uF | Capacitor_SMD:C_0402_1005Metric | C77020 | GRM155R71H104KE14D | 1
C344 | 0.1uF | Capacitor_SMD:C_0402_1005Metric | C77020 | GRM155R71H104KE14D | 1
C345 | 0.1uF | Capacitor_SMD:C_0402_1005Metric | C77020 | GRM155R71H104KE14D | 1
C346 | 0.1uF | Capacitor_SMD:C_0402_1005Metric | C77020 | GRM155R71H104KE14D | 1
C347 | 0.1uF | Capacitor_SMD:C_0402_1005Metric | C77020 | GRM155R71H104KE14D | 1
C348 | 0.1uF | Capacitor_SMD:C_0402_1005Metric | C77020 | GRM155R71H104KE14D | 1
C349 | 0.1uF | Capacitor_SMD:C_0402_1005Metric | C77020 | GRM155R71H104KE14D | 1
C350 | 0.1uF | Capacitor_SMD:C_0402_1005Metric | C77020 | GRM155R71H104KE14D | 1
C351 | 0.1uF | Capacitor_SMD:C_0402_1005Metric | C77020 | GRM155R71H104KE14D | 1
C352 | 0.1uF | Capacitor_SMD:C_0402_1005Metric | C77020 | GRM155R71H104KE14D | 1
C353 | 0.1uF | Capacitor_SMD:C_0402_1005Metric | C77020 | GRM155R71H104KE14D | 1
C354 | 0.1uF | Capacitor_SMD:C_0402_1005Metric | C77020 | GRM155R71H104KE14D | 1
C355 | 0.1uF | Capacitor_SMD:C_0402_1005Metric | C77020 | GRM155R71H104KE14D | 1
C356 | 0.1uF | Capacitor_SMD:C_0402_1005Metric | C77020 | GRM155R71H104KE14D | 1
C357 | 0.1uF | Capacitor_SMD:C_0402_1005Metric | C77020 | GRM155R71H104KE14D | 1
C358 | 0.1uF | Capacitor_SMD:C_0402_1005Metric | C77020 | GRM155R71H104KE14D | 1
C359 | 0.1uF | Capacitor_SMD:C_0402_1005Metric | C77020 | GRM155R71H104KE14D | 1
C360 | 0.1uF | Capacitor_SMD:C_0402_1005Metric | C77020 | GRM155R71H104KE14D | 1
C361 | 0.1uF | Capacitor_SMD:C_0402_1005Metric | C77020 | GRM155R71H104KE14D | 1
C362 | 0.1uF | Capacitor_SMD:C_0402_1005Metric | C77020 | GRM155R71H104KE14D | 1
C363 | 0.1uF | Capacitor_SMD:C_0402_1005Metric | C77020 | GRM155R71H104KE14D | 1
C364 | 0.1uF | Capacitor_SMD:C_0402_1005Metric | C77020 | GRM155R71H104KE14D | 1
C365 | 0.1uF | Capacitor_SMD:C_0402_1005Metric | C77020 | GRM155R71H104KE14D | 1
C366 | 0.1uF | Capacitor_SMD:C_0402_1005Metric | C77020 | GRM155R71H104KE14D | 1
C367 | 0.1uF | Capacitor_SMD:C_0402_1005Metric | C77020 | GRM155R71H104KE14D | 1
C368 | 0.1uF | Capacitor_SMD:C_0402_1005Metric | C77020 | GRM155R71H104KE14D | 1
C369 | 0.1uF | Capacitor_SMD:C_0402_1005Metric | C77020 | GRM155R71H104KE14D | 1
C370 | 0.1uF | Capacitor_SMD:C_0402_1005Metric | C77020 | GRM155R71H104KE14D | 1
C371 | 0.1uF | Capacitor_SMD:C_0402_1005Metric | C77020 | GRM155R71H104KE14D | 1
C372 | 0.1uF | Capacitor_SMD:C_0402_1005Metric | C77020 | GRM155R71H104KE14D | 1
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

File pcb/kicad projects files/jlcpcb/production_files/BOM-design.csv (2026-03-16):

Comment | Designator | Footprint | LCSC
SN74LV1T34DBV | U10,U11,U12,U13,U14,U15,U7,U8,U9 | SOT-23-5 | C100024
1k | R14,R9 | R_0402_1005Metric | C100195
5.1k | R1,R2 | R_0402_1005Metric | C105872
220R | R22,R23,R24,R25,R26,R27,R28,R29,R30 | R_0603_1608Metric | C107696
12K 1% | R13,R18,R8 | R_0402_1005Metric | C114760
2.2K 1% | R11,R16,R21 | R_0402_1005Metric | C114762
MBR230S1F-7 | D1,D2 | D_SOD-123F | C151335
AP2127K-3.3 | U3 | SOT-23-5 | C156285
1uF | C5 | C_0603_1608Metric | C15849
10R | R12,R17,R7 | R_0402_1005Metric | C176108
AP64501SP-13 | U4,U5,U6 | SOIC-8-1EP_3.9x4.9mm_P1.27mm_EP2.95x4.9mm_Mask2.71x3.4mm_ThermalVias | C2071517
1.2nF | C23,C39,C55 | C_0402_1005Metric | C295919
USB_C_Receptacle_USB2.0 | J2 | USB_C_Receptacle_G-Switch_GT-USB-7010ASV | C2988369
12V IN | J4 | CONN-TH_DC-005-2.5A-2.0 | C319099
10uF | C1,C4,C6,C7 | C_0603_1608Metric | C344022
10u 35v | C10,C11,C12,C15,C16,C17,C18,C19,C20,C25,C26,C27,C28,C31,C32,C33,C34,C35,C36,C41,C42,C43,C44,C47,C48,C49,C50,C51,C52,C9 | C_0805_2012Metric | C361063
ESP32-WROOM-32 | U2 | ESP32-WROOM-32 | C529582
ETQ-P3M3R3KVP | L1,L2,L3 | ETQ-P3M_KVP | C542316
100u | C24,C40,C8 | CP_EIA-3528-21_Kemet-B | C597710
10k | R4,R5,R6 | R_0402_1005Metric | C60490
100k | R3 | R_0402_1005Metric | C60491
UMH3N | Q1 | SOT-363_SC-70-6 | C62892
D_Schottky | D5 | D_SMB | C698845
BATTERY | J3 | TerminalBlock_bornier-2_P5.08mm | C709041
SW_Push | SW1,SW2 | SW_Push_1P1T_NO_CK_KMR2 | C72443
CH340C | U1 | SOIC-16_3.9x9.9mm_P1.27mm | C7464026
0.1uF | C100,C101,C102,C103,C104,C105,C106,C107,C108,C109,C110,C111,C112,C113,C114,C115,C116,C117,C118,C119,C120,C121,C122,C123,C124,C125,C126,C127,C128,C129,C13,C130,C131,C132,C133,C134,C135,C136,C137,C138,C139,C140,C141,C142,C143,C144,C145,C146,C147,C148,C149,C150,C151,C152,C153,C154,C155,C156,C157,C158,C159,C160,C161,C162,C163,C164,C165,C166,C167,C168,C169,C170,C171,C172,C173,C174,C175,C176,C177,C178,C179,C180,C181,C182,C183,C184,C185,C186,C187,C188,C189,C190,C191,C192,C193,C194,C195,C196,C197,C198,C199,C2,C200,C201,C202,C203,C204,C205,C206,C207,C208,C209,C21,C210,C211,C212,C213,C214,C215,C216,C217,C218,C219,C220,C221,C222,C223,C224,C225,C226,C227,C228,C229,C230,C231,C232,C233,C234,C235,C236,C237,C238,C239,C240,C241,C242,C243,C244,C245,C246,C247,C248,C249,C250,C251,C252,C253,C254,C255,C256,C257,C258,C259,C260,C261,C262,C263,C264,C265,C266,C267,C268,C269,C270,C271,C272,C273,C274,C275,C276,C277,C278,C279,C280,C281,C282,C283,C284,C285,C286,C287,C288,C289,C29,C290,C291,C292,C293,C294,C295,C296,C297,C298,C299,C3,C300,C301,C302,C303,C304,C305,C306,C307,C308,C309,C310,C311,C312,C313,C314,C315,C316,C317,C318,C319,C320,C321,C322,C323,C324,C325,C326,C327,C328,C329,C330,C331,C332,C333,C334,C335,C336,C337,C338,C339,C340,C341,C342,C343,C344,C345,C346,C347,C348,C349,C350,C351,C352,C353,C354,C355,C356,C357,C358,C359,C360,C361,C362,C363,C364,C365,C366,C367,C368,C369,C37,C370,C371,C372,C373,C374,C375,C376,C377,C378,C379,C380,C381,C382,C383,C384,C385,C386,C387,C388,C389,C390,C391,C392,C393,C394,C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 | C_0402_1005Metric | C77020
20K 1% | R10,R15,R20 | R_0402_1005Metric | C93942
WS2812B | D10,D100,D101,D102,D103,D104,D105,D106,D107,D108,D109,D11,D110,D111,D112,D113,D114,D115,D116,D117,D118,D119,D12,D120,D121,D122,D123,D124,D125,D126,D127,D128,D129,D13,D130,D131,D132,D133,D134,D135,D136,D137,D138,D139,D14,D140,D141,D142,D143,D144,D145,D146,D147,D148,D149,D15,D150,D151,D152,D153,D154,D155,D156,D157,D158,D159,D16,D160,D161,D162,D163,D164,D165,D166,D167,D168,D169,D17,D170,D171,D172,D173,D174,D175,D176,D177,D178,D179,D18,D180,D181,D182,D183,D184,D185,D186,D187,D188,D189,D19,D190,D191,D192,D193,D194,D195,D196,D197,D198,D199,D20,D200,D201,D202,D203,D204,D205,D206,D207,D208,D209,D21,D210,D211,D212,D213,D214,D215,D216,D217,D218,D219,D22,D220,D221,D222,D223,D224,D225,D226,D227,D228,D229,D23,D230,D231,D232,D233,D234,D235,D236,D237,D238,D239,D24,D240,D241,D242,D243,D244,D245,D246,D247,D248,D249,D25,D250,D251,D252,D253,D254,D255,D256,D257,D258,D259,D26,D260,D261,D262,D263,D264,D265,D266,D267,D268,D269,D27,D270,D271,D272,D273,D274,D275,D276,D277,D278,D279,D28,D280,D281,D282,D283,D284,D285,D286,D287,D288,D289,D29,D290,D291,D292,D293,D294,D295,D296,D297,D298,D299,D30,D300,D301,D302,D303,D304,D305,D306,D307,D308,D309,D31,D310,D311,D312,D313,D314,D315,D316,D317,D318,D319,D32,D320,D321,D322,D323,D324,D325,D326,D327,D328,D329,D33,D330,D331,D332,D333,D334,D335,D336,D337,D338,D339,D34,D340,D341,D342,D343,D344,D345,D346,D347,D348,D349,D35,D350,D351,D352,D353,D354,D355,D356,D357,D358,D359,D36,D360,D361,D362,D363,D364,D365,D366,D367,D368,D369,D37,D370,D371,D372,D373,D374,D375,D376,D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 | LED_WS2812B-2020_PLCC4_2.0x2.0mm | C965555
RED | D3,D4,D6,D7 | LED_0603_1608Metric | C965799
nf | C22 | C_0402_1005Metric
MountingHole | H6 | MountingHole_3.2mm_M3
TestPoint | TP4 | TestPoint_Pad_2.0x2.0mm
nf | C46 | C_0402_1005Metric
TestPoint | TP1 | TestPoint_Pad_2.0x2.0mm
nf | C54 | C_0402_1005Metric
nf | C30 | C_0402_1005Metric
MountingHole | H1 | MountingHole_3.2mm_M3
Conn_01x08 | J1 | PinSocket_1x08_P2.54mm_Vertical
MountingHole | H3 | MountingHole_3.2mm_M3
nf | C38 | C_0402_1005Metric
TestPoint | TP3 | TestPoint_Pad_2.0x2.0mm
TestPoint | TP2 | TestPoint_Pad_2.0x2.0mm
nf | C14 | C_0402_1005Metric
MountingHole | H2 | MountingHole_3.2mm_M3
MountingHole | H4 | MountingHole_3.2mm_M3
MountingHole | H5 | MountingHole_3.2mm_M3

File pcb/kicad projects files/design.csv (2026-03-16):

Source: | G:\My Drive\fiverr 2023\projectbarks FO81D43F66982 led battery charging usb\kicad projects files\design.kicad_sch
Date: | 11/12/2023 09:17:35
Tool: | Eeschema 7.0.9
Generator: | C:\Program Files\KiCad\7.0\bin\scripting\plugins/bom_csv_grouped_by_value_with_fp.py
Component Count: | 1091
Ref | Qnty | Value | Cmp name | Footprint | Description | Vendor | DNP
C1, C4, C6, C7 | 4 | 10uF | C | Capacitor_SMD:C_0603_1608Metric | Unpolarized capacitor
C2, C3, C13, C21, C29, C37, C45, C53, C56, C57, C58, C59, C60, C61, C62, C63, C64, C65, C66, C67, C68, C69, C70, C71, C72, C73, C74, C75, C76, C77, C78, C79, C80, C81, C82, C83, C84, C85, C86, C87, C88, C89, C90, C91, C92, C93, C94, C95, C96, C97, C98, C99, C100, C101, C102, C103, C104, C105, C106, C107, C108, C109, C110, C111, C112, C113, C114, C115, C116, C117, C118, C119, C120, C121, C122, C123, C124, C125, C126, C127, C128, C129, C130, C131, C132, C133, C134, C135, C136, C137, C138, C139, C140, C141, C142, C143, C144, C145, C146, C147, C148, C149, C150, C151, C152, C153, C154, C155, C156, C157, C158, C159, C160, C161, C162, C163, C164, C165, C166, C167, C168, C169, C170, C171, C172, C173, C174, C175, C176, C177, C178, C179, C180, C181, C182, C183, C184, C185, C186, C187, C188, C189, C190, C191, C192, C193, C194, C195, C196, C197, C198, C199, C200, C201, C202, C203, C204, C205, C206, C207, C208, C209, C210, C211, C212, C213, C214, C215, C216, C217, C218, C219, C220, C221, C222, C223, C224, C225, C226, C227, C228, C229, C230, C231, C232, C233, C234, C235, C236, C237, C238, C239, C240, C241, C242, C243, C244, C245, C246, C247, C248, C249, C250, C251, C252, C253, C254, C255, C256, C257, C258, C259, C260, C261, C262, C263, C264, C265, C266, C267, C268, C269, C270, C271, C272, C273, C274, C275, C276, C277, C278, C279, C280, C281, C282, C283, C284, C285, C286, C287, C288, C289, C290, C291, C292, C293, C294, C295, C296, C297, C298, C299, C300, C301, C302, C303, C304, C305, C306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 | 495 | 0.1uF | C | Capacitor_SMD:C_0402_1005Metric | Unpolarized capacitor
C5 | 1 | 1uF | C | Capacitor_SMD:C_0603_1608Metric | Unpolarized capacitor
C8, C24, C40 | 3 | 100u | TCJB107M006R0070E | CAPPM3528X210N | Conductive Polymer Solid Electrolytic Chip Capacitors
C9, C10, C11, C12, C15, C16, C17, C18, C19, C20, C25, C26, C27, C28, C31, C32, C33, C34, C35, C36, C41, C42, C43, C44, C47, C48, C49, C50, C51, C52 | 30 | 10u 35v | C | Capacitor_SMD:C_0805_2012Metric | Unpolarized capacitor
C14, C22, C30, C38, C46, C54 | 6 | nf | C | Capacitor_SMD:C_0402_1005Metric | Unpolarized capacitor
C23, C39, C55 | 3 | 1.2nF | C | Capacitor_SMD:C_0402_1005Metric | Unpolarized capacitor
D1, D2 | 2 | MBR230S1F-7 | D_Schottky | Diode_SMD:D_SOD-123F | Schottky diode
D3, D4, D6, D7 | 4 | RED | LED | LED_SMD:LED_0603_1608Metric | Light emitting diode
D5 | 1 | D_Schottky | D_Schottky | Diode_SMD:D_SMB | Schottky diode
D9, D10, D11, D12, D13, D14, D15, D16, D17, D18, D19, D20, D21, D22, D23, D24, D25, D26, D27, D28, D29, D30, D31, D32, D33, D34, D35, D36, D37, D38, D39, D40, D41, D42, D43, D44, D45, D46, D47, D48, D49, D50, D51, D52, D53, D54, D55, D56, D57, D58, D59, D60, D61, D62, D63, D64, D65, D66, D67, D68, D69, D70, D71, D72, D73, D74, D75, D76, D77, D78, D79, D80, D81, D82, D83, D84, D85, D86, D87, D88, D89, D90, D91, D92, D93, D94, D95, D96, D97, D98, D99, D100, D101, D102, D103, D104, D105, D106, D107, D108, D109, D110, D111, D112, D113, D114, D115, D116, D117, D118, D119, D120, D121, D122, D123, D124, D125, D126, D127, D128, D129, D130, D131, D132, D133, D134, D135, D136, D137, D138, D139, D140, D141, D142, D143, D144, D145, D146, D147, D148, D149, D150, D151, D152, D153, D154, D155, D156, D157, D158, D159, D160, D161, D162, D163, D164, D165, D166, D167, D168, D169, D170, D171, D172, D173, D174, D175, D176, D177, D178, D179, D180, D181, D182, D183, D184, D185, D186, D187, D188, D189, D190, D191, D192, D193, D194, D195, D196, D197, D198, D199, D200, D201, D202, D203, D204, D205, D206, D207, D208, D209, D210, D211, D212, D213, D214, D215, D216, D217, D218, D219, D220, D221, D222, D223, D224, D225, D226, D227, D228, D229, D230, D231, D232, D233, D234, D235, D236, D237, D238, D239, D240, D241, D242, D243, D244, D245, D246, D247, D248, D249, D250, D251, D252, D253, D254, D255, D256, D257, D258, D259, D260, D261, D262, D263, D264, D265, D266, D267, D268, D269, D270, D271, D272, D273, 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 | 478 | WS2812B | WS2812B-2020 | LED_SMD:LED_WS2812B-2020_PLCC4_2.0x2.0mm | RGB LED with integrated controller
H1, H2, H3, H4, H5, H6 | 6 | MountingHole | MountingHole | MountingHole:MountingHole_3.2mm_M3 | Mounting Hole without connection
J1 | 1 | Conn_01x08 | Conn_01x08 | Connector_PinSocket_2.54mm:PinSocket_1x08_P2.54mm_Vertical | Generic connector, single row, 01x08, script generated (kicad-library-utils/schlib/autogen/connector/)
J2 | 1 | USB_C_Receptacle_USB2.0 | USB_C_Receptacle_USB2.0 | Connector_USB:USB_C_Receptacle_G-Switch_GT-USB-7010ASV | USB 2.0-only Type-C Receptacle connector
J3 | 1 | BATTERY | Conn_01x02 | TerminalBlock:TerminalBlock_bornier-2_P5.08mm | Generic connector, single row, 01x02, script generated (kicad-library-utils/schlib/autogen/connector/)
J4 | 1 | 12V IN | Barrel_Jack_Switch | Library:CONN-TH_DC-005-2.5A-2.0 | DC Barrel Jack with an internal switch
L1, L2, L3 | 3 | ETQ-P3M3R3KVP | INDUCTOR | Library:ETQ-P3M_KVP | Inductor symbol for simulation only
Q1 | 1 | UMH3N | UMH3N | Package_TO_SOT_SMD:SOT-363_SC-70-6 | 0.1A Ic, 50V Vce, Dual NPN Input Resistor Transistors, SOT-363
R1, R2 | 2 | 5.1k | R | Resistor_SMD:R_0402_1005Metric | Resistor
R3 | 1 | 100k | R | Resistor_SMD:R_0402_1005Metric | Resistor
R4, R5, R6 | 3 | 10k | R | Resistor_SMD:R_0402_1005Metric | Resistor
R7, R12, R17 | 3 | 10R | R | Resistor_SMD:R_0402_1005Metric | Resistor
R8, R13, R18 | 3 | 12K 1% | R | Resistor_SMD:R_0402_1005Metric | Resistor
R9, R14 | 2 | 1k | R | Resistor_SMD:R_0402_1005Metric | Resistor
R10, R15, R20 | 3 | 20K 1% | R | Resistor_SMD:R_0402_1005Metric | Resistor
R11, R16, R21 | 3 | 2.2K 1% | R | Resistor_SMD:R_0402_1005Metric | Resistor
R22, R23, R24, R25, R26, R27, R28, R29, R30 | 9 | 220R | R | Resistor_SMD:R_0603_1608Metric | Resistor
SW1, SW2 | 2 | SW_Push | SW_Push | Button_Switch_SMD:SW_Push_1P1T_NO_CK_KMR2 | Push button switch, generic, two pins
TP1, TP2, TP3, TP4 | 4 | TestPoint | TestPoint | TestPoint:TestPoint_Pad_2.0x2.0mm | test point
U1 | 1 | CH340C | CH340C | Package_SO:SOIC-16_3.9x9.9mm_P1.27mm | USB serial converter, UART, SOIC-16
U2 | 1 | ESP32-WROOM-32 | ESP32-WROOM-32 | Library:ESP32-WROOM-32 | RF Module, ESP32-D0WDQ6 SoC, Wi-Fi 802.11b/g/n, Bluetooth, BLE, 32-bit, 2.7-3.6V, onboard antenna, SMD
U3 | 1 | AP2127K-3.3 | AP2127K-3.3 | Package_TO_SOT_SMD:SOT-23-5 | 300mA low dropout linear regulator, shutdown pin, 2.5V-6V input voltage, 3.3V fixed positive output, SOT-23-5
U4, U5, U6 | 3 | AP64501SP-13 | AP64351 | Library:SOIC-8-1EP_3.9x4.9mm_P1.27mm_EP2.95x4.9mm_Mask2.71x3.4mm_ThermalVias
U7, U8, U9, U10, U11, U12, U13, U14, U15 | 9 | SN74LV1T34DBV | SN74LV1T34DBV | Package_TO_SOT_SMD:SOT-23-5 | Single Power Supply, Single Buffer GATE, CMOS Logic, Level Shifter, SOT-23-5

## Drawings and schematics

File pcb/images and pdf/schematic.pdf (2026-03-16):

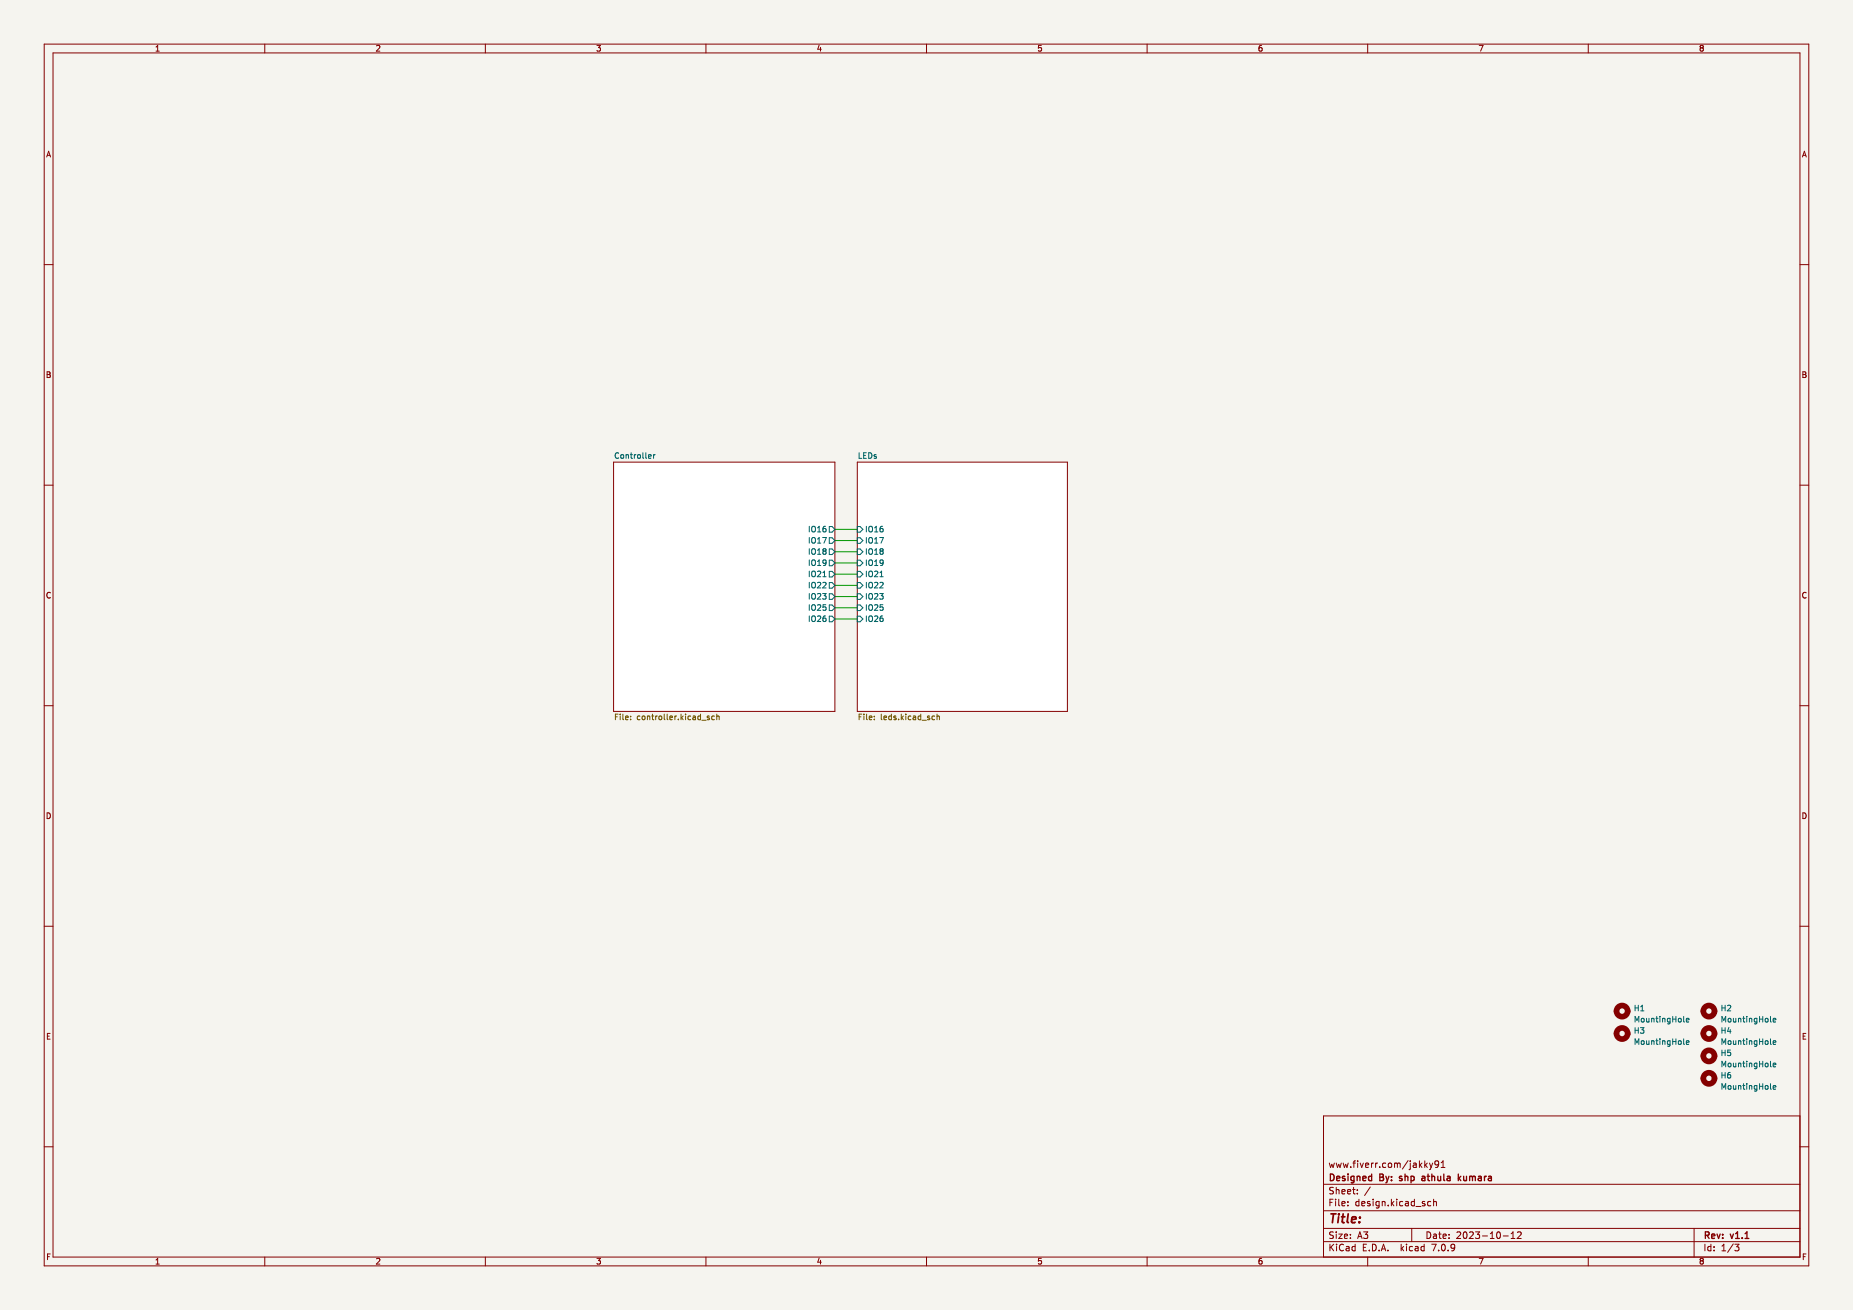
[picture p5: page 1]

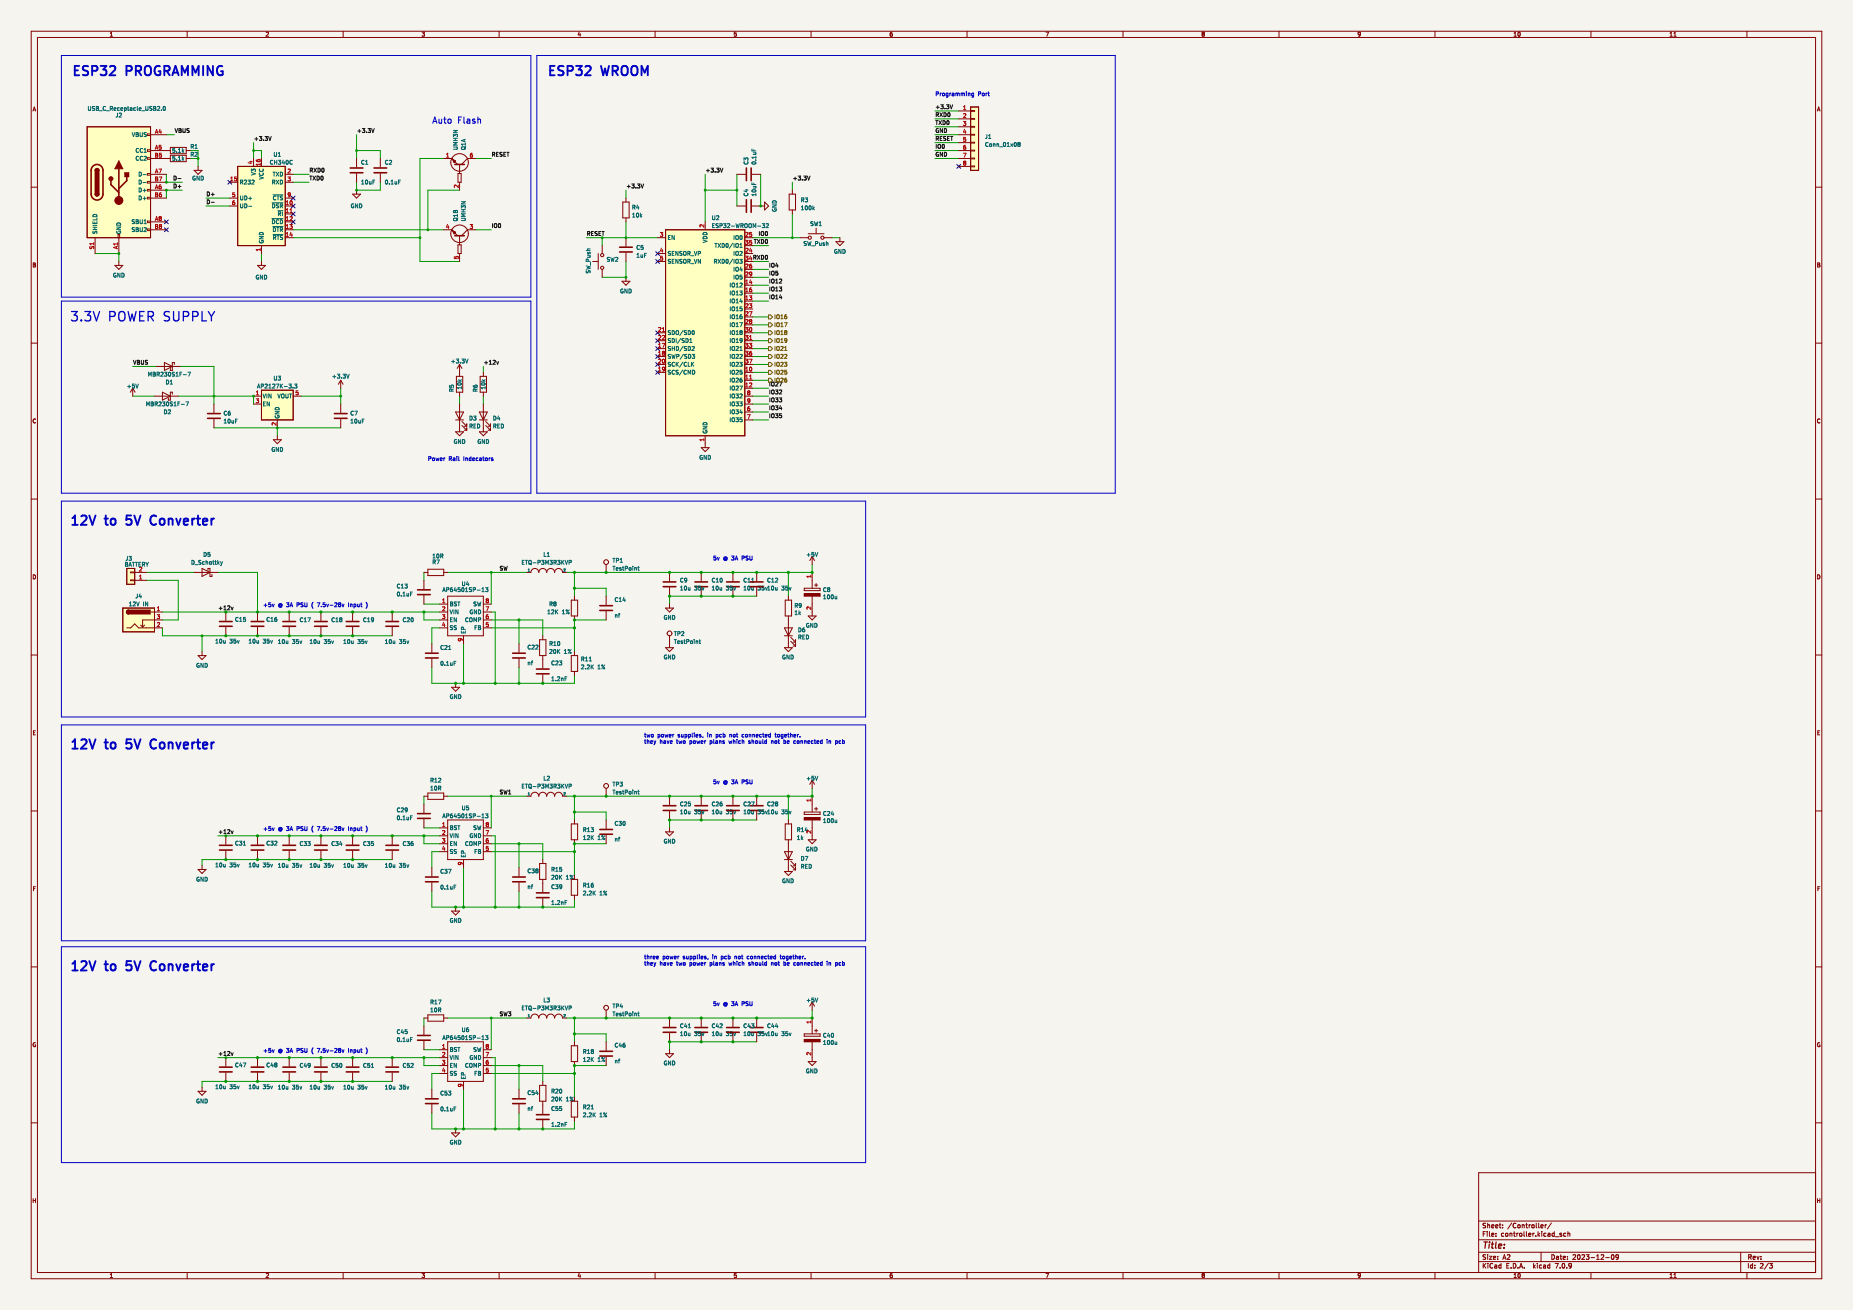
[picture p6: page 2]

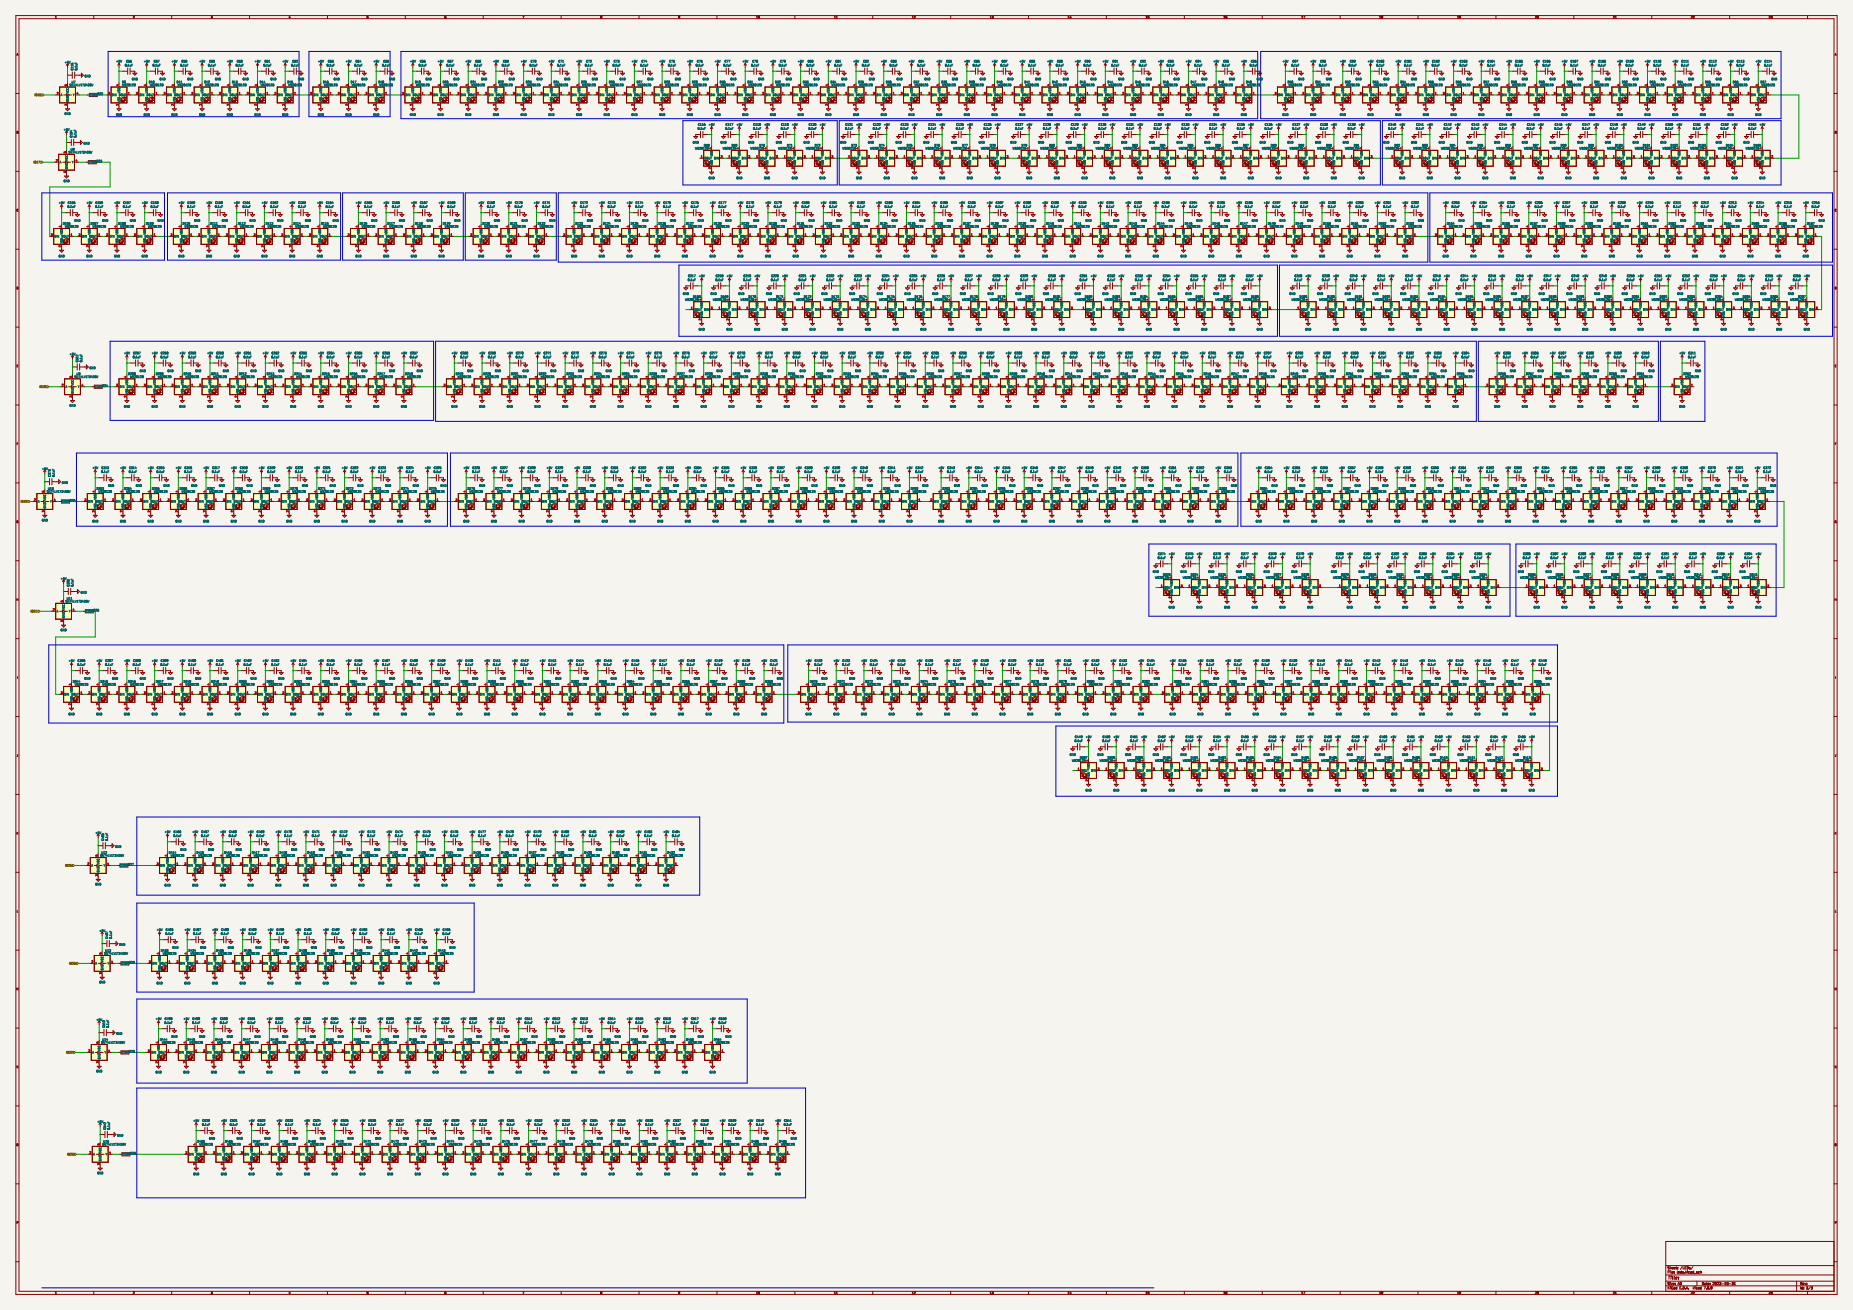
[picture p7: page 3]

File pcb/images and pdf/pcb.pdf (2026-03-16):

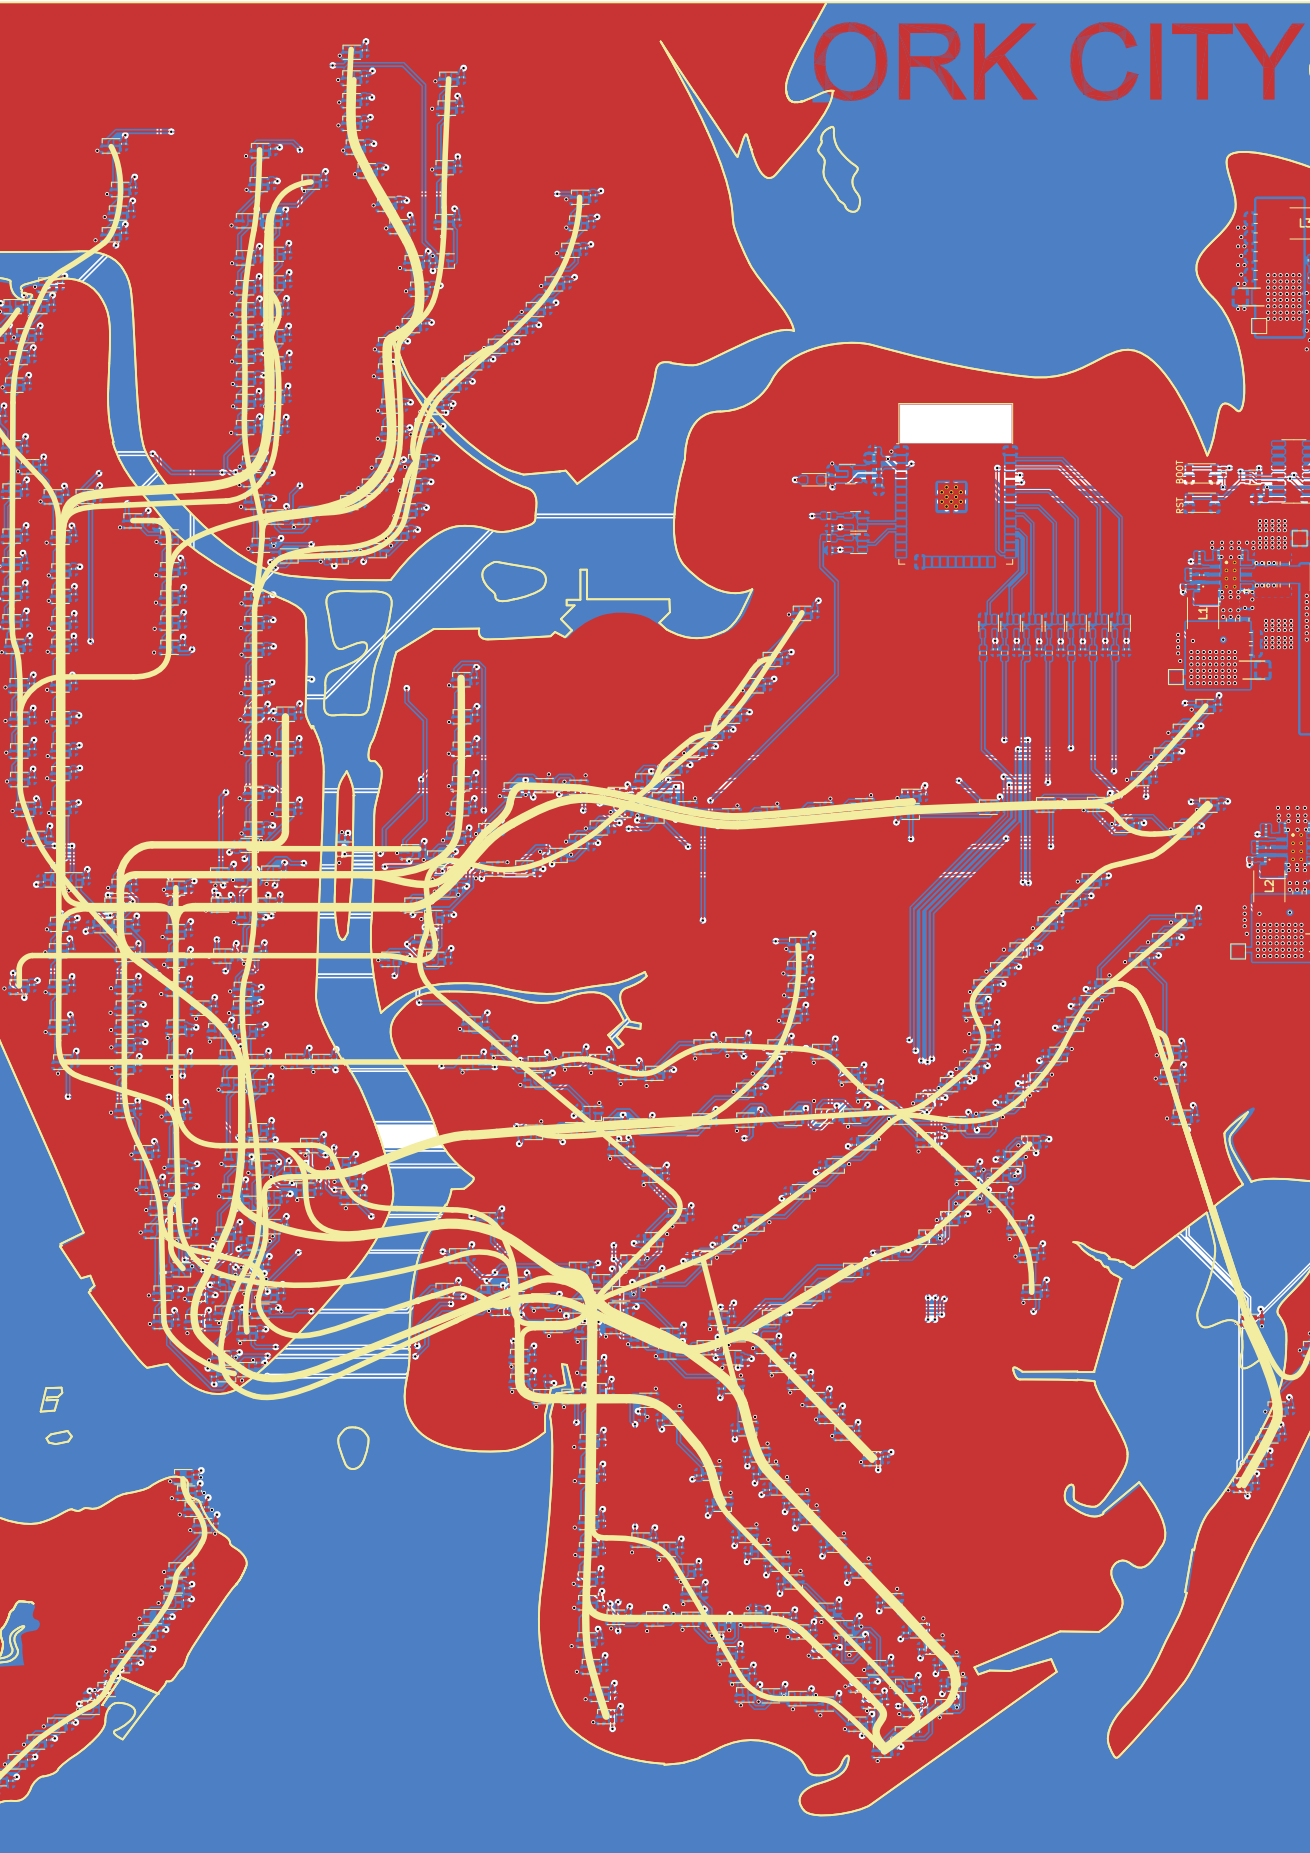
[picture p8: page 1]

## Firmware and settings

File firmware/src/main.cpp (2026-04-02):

#include "config/board_config.hpp"
#include "config/constants.hpp"
#include "core/channel.hpp"
#include "core/triple_buffer.hpp"
#include "data/board_snapshot.hpp"
#include "data/diag_pad.hpp"
#include "data/transit_snapshot.hpp"
#include "esp_ghota.h"
#include "esp_heap_caps.h"
#include "esp_log.h"
#include "esp_netif.h"
#include "esp_spiffs.h"
#include "esp_system.h"
#include "esp_wifi.h"
#include "freertos/FreeRTOS.h"
#include "freertos/task.h"
#include "hal/led_driver.hpp"
#include "log/device_log.hpp"
#include "net/state_client.hpp"
#include "nvs_flash.h"
#include "script/lua_runtime.hpp"
#include "serial/serial_handler.hpp"
#include "wifi_manager.h"

#include <atomic>
#include <cstdio>
#include <cstring>

static const char* TAG = "main";

// All shared state — static in file scope, process lifetime
static BoardHwConfig s_hw_config;
static LedDriver s_led_driver;
static DoubleBuffer<TransitSnapshot> s_transit_buf;
static BoardStore s_board_store;
static ScriptChannel s_script_chan;
static DiagPad s_diag;
static std::atomic<bool> s_ota_active{false};
static std::atomic<bool> s_http_active{false};

static ghota_client_handle_t* s_ghota = nullptr;

static void ghota_event_handler(void* arg, esp_event_base_t base, int32_t id, void* data) {
    ghota_event_e event = static_cast<ghota_event_e>(id);
    DLOG_I(TAG, "OTA event: %s", ghota_get_event_str(event));

    switch (event) {
    case GHOTA_EVENT_START_CHECK:
    case GHOTA_EVENT_START_UPDATE:
        s_ota_active.store(true, std::memory_order_release);
        DLOG_W(TAG, "Free heap: %lu bytes", (unsigned long)esp_get_free_heap_size());
        break;
    case GHOTA_EVENT_NOUPDATE_AVAILABLE:
    case GHOTA_EVENT_UPDATE_FAILED:
    case GHOTA_EVENT_FINISH_UPDATE:
        s_ota_active.store(false, std::memory_order_release);
        break;
    default:
        break;
    }
}

static std::atomic<bool> s_wifi_connected{false};

static void cb_wifi_got_ip(void* pvParameter) {
    DLOG_I(TAG, "WiFi connected");
    s_wifi_connected.store(true, std::memory_order_release);
}

static bool load_local_script(ScriptChannel& chan) {
    esp_vfs_spiffs_conf_t conf = {
        .base_path = "/scripts",
        .partition_label = "storage",
        .max_files = 2,
        .format_if_mount_failed = true,
    };
    esp_err_t ret = esp_vfs_spiffs_register(&conf);
    if (ret != ESP_OK) {
        DLOG_W(TAG, "SPIFFS mount failed: %s", esp_err_to_name(ret));
        return false;
    }

    FILE* f = fopen("/scripts/local.lua", "r");
    if (!f)
        return false;

    fseek(f, 0, SEEK_END);
    long size = ftell(f);
    fseek(f, 0, SEEK_SET);

    if (size <= 0 || size > (long)kScriptMaxSize) {
        fclose(f);
        return false;
    }

    char* buf = (char*)malloc(size + 1);
    if (!buf) {
        fclose(f);
        return false;
    }

    fread(buf, 1, size, f);
    buf[size] = '\0';
    fclose(f);

    DLOG_I(TAG, "Loaded local script: %ld bytes", size);
    chan.send(buf); // ownership transferred
    return true;
}

extern "C" void app_main(void) {
    DLOG_W(TAG,
           "=== NYC Subway PCB v%s === reset_reason=%d",
           kFirmwareVersion,
           (int)esp_reset_reason());
    DLOG_W(TAG,
           "HEAP: %lu free, %lu min, %lu largest block",
           (unsigned long)esp_get_free_heap_size(),
           (unsigned long)esp_get_minimum_free_heap_size(),
           (unsigned long)heap_caps_get_largest_free_block(MALLOC_CAP_8BIT));

    // 1. Initialize logging
    device_log_init();

    // 2. NVS (with erase recovery)
    esp_err_t ret = nvs_flash_init();
    if (ret == ESP_ERR_NVS_NO_FREE_PAGES || ret == ESP_ERR_NVS_NEW_VERSION_FOUND) {
        ESP_ERROR_CHECK(nvs_flash_erase());
        ret = nvs_flash_init();
    }
    ESP_ERROR_CHECK(ret);
    DLOG_W(TAG, "HEAP after NVS: %lu free", (unsigned long)esp_get_free_heap_size());

    // 3. Load board hardware config
    BoardHwConfig::load(s_hw_config);

    // 4. LEDs dark BEFORE WiFi (current draw)
    ESP_ERROR_CHECK(s_led_driver.init(&s_hw_config));
    s_led_driver.clear();
    DLOG_W(TAG, "LEDs cleared. heap=%lu", (unsigned long)esp_get_free_heap_size());

    // 5. Mount SPIFFS + load local script (if any)
    bool has_local_script = load_local_script(s_script_chan);
    if (has_local_script) {
        DLOG_I(TAG, "Local script queued for execution");
    }

    // 6. Start serial handler -- USB available immediately
    SerialHandler::start({
        .diag = &s_diag,
        .hw_config = &s_hw_config,
        .led_driver = &s_led_driver,
        .script_chan = &s_script_chan,
    });

    // 7. Initialize shared state mutexes
    s_diag.init();
    s_board_store.init();

    // 8. Start Lua render -- board renders immediately (with local script if loaded)
    LuaRuntime::start(
        s_transit_buf, s_board_store, s_script_chan, s_diag, s_http_active, s_led_driver);

    // 9. WiFi
    DLOG_W(TAG, "Starting WiFi manager...");
    wifi_manager_start();
    wifi_manager_set_callback(WM_EVENT_STA_GOT_IP, &cb_wifi_got_ip);

    // 10. Wait for WiFi with timeout (not infinite)
    DLOG_W(TAG,
           "Waiting for WiFi (timeout %ds). heap=%lu",
           kWifiTimeoutSec,
           (unsigned long)esp_get_free_heap_size());
    int wifi_wait = 0;
    while (!s_wifi_connected.load(std::memory_order_acquire)) {
        vTaskDelay(pdMS_TO_TICKS(1000));
        wifi_wait++;
        if (wifi_wait % 5 == 0) {
            DLOG_W(TAG, "Still waiting for WiFi... (%ds)", wifi_wait);
        }
        if (wifi_wait >= kWifiTimeoutSec) {
            DLOG_W(TAG, "WiFi timeout after %ds -- continuing without network", wifi_wait);
            break;
        }
    }

    bool wifi_ok = s_wifi_connected.load(std::memory_order_acquire);

    if (wifi_ok) {
        DLOG_W(TAG, "WiFi connected. heap=%lu", (unsigned long)esp_get_free_heap_size());

        // 11. OTA (only if WiFi connected)
        ghota_config_t ghota_config = {};
        std::strncpy(
            ghota_config.filenamematch, "firmware.bin", sizeof(ghota_config.filenamematch) - 1);
        ghota_config.hostname = const_cast<char*>("api.github.com");
        ghota_config.orgname = const_cast<char*>("ProjectBarks");
        ghota_config.reponame = const_cast<char*>("subway-pcb");
        ghota_config.updateInterval = kOtaCheckIntervalMin;
        s_ghota = ghota_init(&ghota_config);
        if (s_ghota) {
            esp_event_handler_register(
                GHOTA_EVENTS, ESP_EVENT_ANY_ID, &ghota_event_handler, nullptr);
            ghota_start_update_timer(s_ghota);
            DLOG_I(TAG, "OTA checker started (every %lu min)", (unsigned long)kOtaCheckIntervalMin);
        }

        // 12. State polling (only if WiFi connected)
        StateClient::start(
            s_transit_buf, s_board_store, s_script_chan, s_diag, s_ota_active, s_http_active);
    } else {
        DLOG_W(TAG, "Running in offline mode -- no OTA or state polling");
    }

    DLOG_W(TAG,
           "All services running. heap=%lu min=%lu wifi=%s",
           (unsigned long)esp_get_free_heap_size(),
           (unsigned long)esp_get_minimum_free_heap_size(),
           wifi_ok ? "yes" : "no");
}

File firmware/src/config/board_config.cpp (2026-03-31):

#include "config/board_config.hpp"

#include "log/device_log.hpp"

extern "C" {
#include "nvs.h"
#include "nvs_flash.h"
}

#include <cstring>

static const char* TAG = "board_config";

// Compile-time defaults (matching original board_config.c values)
static constexpr uint8_t kDefaultStripGpios[] = {16, 17, 18, 19, 21, 22, 23, 25, 26};
static constexpr uint16_t kDefaultStripLedCounts[] = {97, 102, 55, 81, 70, 21, 22, 19, 11};
static constexpr uint8_t kDefaultNumStrips = 9;
static constexpr uint16_t kDefaultTotalLeds = 478;
static constexpr uint8_t kDefaultSpiStripIdx = 8;

void BoardHwConfig::load(BoardHwConfig& cfg) {
    cfg = BoardHwConfig{};

    // Fill with compile-time defaults
    cfg.num_strips = kDefaultNumStrips;
    cfg.total_leds = kDefaultTotalLeds;
    cfg.spi_strip_index = kDefaultSpiStripIdx;
    for (int i = 0; i < kDefaultNumStrips; i++) {
        cfg.strip_gpios[i] = kDefaultStripGpios[i];
        cfg.strip_led_counts[i] = kDefaultStripLedCounts[i];
    }

    // Try NVS overrides
    nvs_handle_t nvs;
    if (nvs_open("subway", NVS_READONLY, &nvs) != ESP_OK) {
        DLOG_I(TAG, "Using defaults: %d strips, %d LEDs", cfg.num_strips, cfg.total_leds);
        return;
    }

    uint8_t num_strips = 0;
    if (nvs_get_u8(nvs, "hw_num_strips", &num_strips) == ESP_OK && num_strips > 0 &&
        num_strips <= kMaxStrips) {
        cfg.num_strips = num_strips;

        // Read GPIO blob
        size_t len = num_strips;
        uint8_t gpio_buf[kMaxStrips];
        if (nvs_get_blob(nvs, "hw_strip_gpios", gpio_buf, &len) == ESP_OK && len == num_strips) {
            std::memcpy(cfg.strip_gpios, gpio_buf, num_strips);
        }

        // Read LED count blob (uint16_t array)
        len = num_strips * sizeof(uint16_t);
        uint16_t led_buf[kMaxStrips];
        if (nvs_get_blob(nvs, "hw_strip_leds", led_buf, &len) == ESP_OK &&
            len == num_strips * sizeof(uint16_t)) {
            std::memcpy(cfg.strip_led_counts, led_buf, len);
            // Recompute total
            cfg.total_leds = 0;
            for (int i = 0; i < num_strips; i++) {
                cfg.total_leds += cfg.strip_led_counts[i];
            }
        }

        uint8_t spi_idx = 0;
        if (nvs_get_u8(nvs, "hw_spi_strip", &spi_idx) == ESP_OK) {
            cfg.spi_strip_index = spi_idx;
        }
    }

    nvs_close(nvs);
    DLOG_I(TAG,
           "Board config: %d strips, %d LEDs, SPI strip=%d",
           cfg.num_strips,
           cfg.total_leds,
           cfg.spi_strip_index);
}

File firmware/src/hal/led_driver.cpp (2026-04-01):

#include "hal/led_driver.hpp"

#include "data/diag_pad.hpp"
#include "esp_log.h"
#include "led_strip.h"
#include "log/device_log.hpp"

#include <algorithm>
#include <cstring>

static const char* TAG = "led_driver";

esp_err_t LedDriver::init(const BoardHwConfig* hw) {
    hw_ = hw;

    // Compute strip offsets into flat pixel buffer
    uint16_t offset = 0;
    for (int i = 0; i < hw->num_strips; i++) {
        strip_offsets_[i] = offset;
        offset += hw->strip_led_counts[i];
    }

    std::fill(std::begin(pixel_buf_), std::end(pixel_buf_), Rgb{});

    DLOG_I(TAG,
           "LED driver initialized (%d strips, %d LEDs, SPI time-multiplexed)",
           hw->num_strips,
           hw->total_leds);
    return ESP_OK;
}

esp_err_t LedDriver::refresh_strip_spi(int strip_idx) const {
    led_strip_config_t cfg = {
        .strip_gpio_num = hw_->strip_gpios[strip_idx],
        .max_leds = hw_->strip_led_counts[strip_idx],
        .led_pixel_format = LED_PIXEL_FORMAT_GRB,
        .led_model = LED_MODEL_WS2812,
    };
    led_strip_spi_config_t spi_cfg = {
        .spi_bus = SPI2_HOST,
        .flags = {.with_dma = true},
    };

    led_strip_handle_t handle = nullptr;
    esp_err_t ret = led_strip_new_spi_device(&cfg, &spi_cfg, &handle);
    if (ret != ESP_OK)
        return ret;

    // Load pixel data from Rgb buffer
    uint16_t offset = strip_offsets_[strip_idx];
    for (uint16_t p = 0; p < hw_->strip_led_counts[strip_idx]; p++) {
        const Rgb& px = pixel_buf_[offset + p];
        led_strip_set_pixel(handle, p, px.r, px.g, px.b);
    }

    ret = led_strip_refresh(handle);

    // Tear down -- frees the SPI bus for the next strip
    led_strip_del(handle);

    return ret;
}

bool LedDriver::map_pixel(uint32_t global_index, uint8_t* out_strip, uint16_t* out_pixel) const {
    if (!hw_)
        return false;
    for (uint8_t i = 0; i < hw_->num_strips; i++) {
        uint16_t offset = strip_offsets_[i];
        if (global_index >= offset && global_index < offset + hw_->strip_led_counts[i]) {
            *out_strip = i;
            *out_pixel = static_cast<uint16_t>(global_index - offset);
            return true;
        }
    }
    return false;
}

esp_err_t LedDriver::refresh(DiagPad& diag) {
    if (!hw_)
        return ESP_ERR_INVALID_STATE;

    int ok = 0;
    int fail = 0;
    for (int i = 0; i < hw_->num_strips; i++) {
        esp_err_t ret = refresh_strip_spi(i);
        if (ret != ESP_OK) {
            ESP_LOGW(TAG, "Strip %d SPI refresh failed: %s", i, esp_err_to_name(ret));
            fail++;
        } else {
            ok++;
        }
    }

    diag.strip_ok.store(ok, std::memory_order_relaxed);
    diag.strip_fail.store(fail, std::memory_order_relaxed);

    return ESP_OK;
}

esp_err_t LedDriver::clear() {
    if (!hw_)
        return ESP_ERR_INVALID_STATE;

    std::fill(pixel_buf_, pixel_buf_ + hw_->total_leds, Rgb{});

    // Push zeroed pixels to all strips directly (no diag update needed)
    for (int i = 0; i < hw_->num_strips; i++) {
        esp_err_t ret = refresh_strip_spi(i);
        if (ret != ESP_OK) {
            ESP_LOGW(TAG, "Strip %d SPI clear failed: %s", i, esp_err_to_name(ret));
        }
    }

    return ESP_OK;
}

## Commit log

2026-03-15 feat: initial MCP capture tool and LED mapper bridge
    - mcp/capture.py: camera setup UI with zoom loupe, perspective warp,
    contrast enhancement, sobel edge output, MCP server mode
    - mapper/bridge/bridge.ino: Arduino serial bridge for LED mapping
    - .gitignore: excludes captures, config, test scripts, subprojects
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2026-03-16 feat: add Go server, ESP32 firmware, web visualizer, and tools
    - Go server with MTA feed polling, pixel rendering, protobuf API
    - ESP32 firmware with WiFi, LED strips, protobuf pixel client
    - Web visualizer with KiCad SVG board background
    - Refactored board.js as shared PCB renderer
    - tools/debug-firmware: Arduino PlatformIO serial LED control
    - tools/led-debugger-ui: Python web UI for click-to-light debugging
    - tools/led-mapping-ui: Original mapper tool (moved from mapper/)
    - Correct strip sizes [97,102,55,81,70,21,22,19,11] = 478 LEDs
    - Correct LED chain ordering from PCB netlist tracing
    - Brownout detector disabled for stable WiFi init
    [debugger.py, main.cpp, main.py]
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2026-03-16 fix: remove tracked secrets, binaries, and generated files
    - Untrack wifi.txt, serial.log, subway-server binary
    - Untrack sdkconfig.esp32dev, uv.lock
    - Add *.lock to gitignore
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2026-03-17 feat: switch all LED strips to time-multiplexed SPI DMA
    Each strip gets exclusive SPI2 bus access sequentially: create SPI
    device, DMA transfer pixel data, destroy device, next strip. All 9
    strips are now WiFi-immune (no RMT interrupt vulnerability).
    Also: pure red route colors, full-brightness wire values with
    firmware-side brightness scaling, core pinning reverted (didn't help).
2026-03-17 chore: remove unused firmware files, add X-Device-ID header
    Remove:
    - renderer.c/.h (unused since switch to server-side pixel rendering)
    - station_map.c/.h (unused since switch to server-side mapping)
    - gen_station_map.py (no longer needed)
    - Old SubwayState/Station/Train nanopb options (only PixelFrame used)
    Add:
    - X-Device-ID header (ESP32 MAC address) on every pixel request
    - esp_mac.h include for reading device MAC
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2026-03-17 ci: add GitHub Actions, Docker build, and Railway deploy
    - firmware.yml: build ESP32 firmware, release on tags
    - lint.yml: Go vet, Python compile check, PlatformIO build
    - deploy.yml: deploy server to Railway
    - Dockerfile: Go 1.26 multi-stage build with repo-root context
    - Fix protobuf panic on malformed MTA feed data
    - Railway deployed at https://subway-pcb-production.up.railway.app
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2026-03-17 feat: OTA version checking works, download needs redirect fix
    OTA checks GitHub releases every 1 min, finds new versions correctly.
    Download fails because esp_https_ota doesn't follow 302 redirects from GitHub.
    TODO: proxy firmware binary through Railway server, or pre-resolve redirect.
2026-03-17 fix: template rendering, script ordering, and UI fixes for web dashboard
    - Rewrite template renderer to clone base templates per page (prevents
    {{define "content"}} collisions between pages)
    - Move board.js to <head> so Board class is available before page scripts
    - Extract board_grid partial for HTMX auto-refresh endpoint
    - Fix template field names (.FirmwareVer, .IsBuiltIn, .RouteColors map iteration)
    - Add led_map.json to static dir for client-side theme preview
    - Fix theme_form to use data-route-key attributes and proper color collection
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2026-03-18 refactor: split server into service/backend + service/frontend
    - Move server/ to service/backend/ for clearer project structure
    - Add TypeScript + Vite frontend in service/frontend/
    - Add static file serving (--static-dir flag) for local dev
    - Add board-viewer, pcb-glb-generator, and led-mapping tools
    - Fix vite config (remove stale standalone entry)
    - Fix board.svg path for static serving
    - Update .gitignore for new paths and build output
2026-03-18 fix: update Dockerfile and Railway config for new project structure
    - Update Dockerfile paths from server/ to service/backend/
    - Add multi-stage frontend build (node + vite)
    - Add railway.json pointing to new Dockerfile location
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2026-03-19 feat: add HostRestriction middleware and fix Dockerfile templ generation
    Add HostRestriction middleware that blocks requests from RESTRICTED_HOST
    on app-only routes. Device routes (/api/v1/pixels) sit outside the
    restriction group. Configurable via RESTRICTED_HOST env var; no-op when
    unset. Add templ generate step to Dockerfile to fix deploy failures.
    [main.py]
2026-03-19 chore: add ty type checking for Python tools
    Add ty (astral.sh/ty) to Python lint pipeline alongside ruff. Fix type
    errors in led-debugger-ui (nullable controller, log_message signature).
    Exclude pcb-glb-generator from ty due to incomplete third-party stubs.
    [debugger.py]
2026-03-19 fix: resolve CI failures and include all Python tools in ty
    Revert biome's unsafe parentElement?. conversion back to parentElement!
    to fix TypeScript errors. Add --ignore unresolved-import to ty for CI
    (hardware deps not installed). Fix ty errors in pcb-glb-generator:
    Image.LANCZOS -> Image.Resampling.LANCZOS, add trimesh.visual imports,
    type-annotate trimesh.load as Scene, narrow geom_name with isinstance.
2026-03-20 feat: add plugin system, community browser, editor, landing page, and lint fixes
    - Replace mode system with plugin registry supporting built-in and user-installed Lua plugins
    - Add community plugin browser with search, install/uninstall, and code viewer
    - Add Lua plugin editor with live preview, config field editor, and publish flow
    - Add landing page with 3D hero board, scroll animations, and feature showcase
    - Refactor frontend into modular structure (board/, editor/, hero-board/, serial/)
    - Add WebSerial support for USB board communication
    - Extend store interfaces for plugin, preset, and access management
    - Add Tailwind theme, animations, and Prism Lua syntax highlighting
    - Fix all biome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
2026-03-20 fix: build frontend assets in GitHub Pages workflow
    The landing page referenced /static/dist/main.css and landing.js but
    the workflow never built the frontend, so CSS and JS failed to load.
2026-03-20 fix: track GLB and LED positions so GitHub Pages can serve them
2026-03-20 refactor: merge backend/frontend into unified service dir, use make in CI
    - Flatten service/backend + service/frontend into service/
    - Rewrite lint and pages workflows to use Makefile targets
    - Add frontend/typecheck and fix site/build to include frontend assets
    - Comment out community showcase section on landing page
    - Fix unused type-ignore in pcb-glb-generator
2026-03-20 feat: add versioned board model concept with plugin compatibility
    Introduce a file-based board model system that replaces hardcoded
    strip sizes, LED counts, and board names. Each board model is versioned
    on disk (e.g. boards/nyc-subway/v1/board.json) and loaded into memory
    at startup.
    - Add BoardManifest, BoardData types and LoadAllBoards loader
    - Add BoardModelID to Device model (both bolt and MySQL stores)
    - Add RequiredFeatures() to Plugin interface for board compatibility
    - Remove hardcoded stripSizes/totalLEDs from pixels.go and snake.go
    - Snake plugin now uses ctx.Strips from RenderContext
    - Track plugin declares "mta-stations" feature requirement
    - Server filters plugins by board com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
2026-03-20 refactor: remove legacy files, rename branding to Train PCB
    Delete unused legacy files (led_map.json, leds.json, board.svg,
    board_paths.json, led_positions.json, subway-pcb.glb at old paths)
    and the old hero-board and board.ts modules replaced by board-viewer.
    Rename branding from "LED PCB" / "NYC Subway PCB" to "Train PCB"
    across nav, layout, dashboard, landing, and footer templates.
    Remove stale Board global and vite proxy entries for deleted files.
2026-03-21 feat: add Lua runtime for plugin rendering on firmware and frontend
    Add a Lua-based plugin execution system across the full stack:
    Firmware:
    - Add Lua 5.4.7 ESP-IDF component (sources downloaded per README)
    - Add lua_runtime: Lua VM with MTA/LED/config host functions
    - Add render_context: shared state between state_client and lua_runtime
    - Add state_client: polls DeviceState/DeviceBoard/DeviceScript endpoints
    - Regenerate nanopb protobuf with new message types (Train, Station,
    DeviceState, DeviceBoard, DeviceScript)
    - Fix nanopb decoding to use static arrays (not callbacks)
    - Increase OTA partition size to 1.5MB for Lua interpreter
    Backend:
    - Add LuaSource() to Plugin interface; track/sn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
    [partitions.csv]
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2026-03-21 fix: board detail page config selector, mobile hero adjustments
    Fix collectInitialConfig() and updatePreviewColor() to query config
    inputs by name attribute instead of nonexistent data-route-key, which
    caused the Track plugin's 3D preview to render with no route colors.
    Also adjust hero board height and camera distance for mobile.
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2026-03-21 fix: board page browse previews and plugin switch rendering
    - Board 3D viewer now reloads Lua source on plugin/preset switch via
    data-lua-source attribute on #controls, updated after HTMX swaps
    - Browse plugins tab reuses shared preview-controller (initPreviews)
    instead of custom rendering code — same lazy-load, hover animation,
    and MTA state as community and dashboard pages
    - Each browse card uses its own plugin's default config, not the active
    plugin's config, so previews show correct colors
    - Add DefaultConfigMap to plugin package; board and community helpers
    both use it to eliminate duplicated config extraction logic
    - Add ActiveLuaSource to BoardData, populated from built-in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
2026-03-21 fix: mobile nav menu not opening on tap
    Remove inline onclick handler from mobile menu button that conflicted
    with the JS initNav() click listener — both ran on click, causing the
    menu to toggle open then immediately close. Now only initNav() controls
    the toggle. Also align icon span IDs (menu-icon-open/close) between
    the template and JS.
2026-03-21 refactor: code cleanup — AnimXYZ migration, dead code removal, extract shared helpers, split server.go
    - Migrate all enter/exit animations to AnimXYZ composable system, delete manual @keyframes and toast.css
    - Remove unused Go code: Ingest() shim, RequireAuth middleware, discarded NewAggregator param
    - Remove unused TS/proto: color.ts, board/index.ts barrel, RGB type, ConfigFieldType enum
    - Extract shared TS helpers: loadBoardData(), pollMtaState(), collectConfig()
    - Add Go generic helpers: getOrError[T], requireOwnerOrAdmin; fix swallowed errors in render helpers
    - Split server.go (1052 lines) into 6 domain-specific files
    - Extract writePluginButton helper with XSS-safe HTML escaping
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2026-03-22 refactor: simplify device middleware, rename API files, add errgroup for concurrent queries
    - Remove HardwareFromContext context plumbing — handlers read headers directly
    - Move header constants to middleware package, delete device_constants.go
    - Simplify DeviceAutoRegister middleware (deduplicate upsert logic)
    - Add errgroup for concurrent plugin+device queries in buildDeviceConfig
    - Propagate errors from resolveDeviceLua and buildDeviceConfig
    - Rename server_*.go → handle_*.go / api_*.go for clarity
    - Extract install-button.templ from plugin-card.templ
2026-03-22 fix: responsive community header, button styling consistency, preview re-rendering
    - Stack community page header vertically on mobile so Create Plugin
    button no longer overlaps the title
    - Switch btn-outline from rounded-full to rounded-lg for consistency
    - Use btn-primary class in editor config and login pages
    - Clean up preview lifecycle (destroy/re-init on HTMX swaps) and
    eagerly render cards already in the viewport after swap
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2026-03-22 feat: add Cucumber BDD e2e tests with Playwright
    Add end-to-end test suite covering all pages (health, navigation,
    dashboard, community, editor) across desktop and mobile viewports.
    68 scenarios validate server health, page rendering, HTMX interactions,
    canvas previews, and the Preact plugin editor lifecycle.
    - Cucumber + Playwright + tsx for BDD test runner
    - Custom PlaywrightWorld with per-scenario browser lifecycle
    - Go server auto-built and started in BeforeAll, fresh bbolt DB per run
    - Failure screenshots captured and attached to HTML/JSON reports
    - Minimal 9-LED test board for deterministic canvas validation
    - Makefile targets: e2e/install, e2e/test, e2e/test-headed
    - GitHub Actions C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
2026-03-22 fix: dashboard empty state, Makefile codegen, simplified CI workflow
    - Fix dashboard test to match empty state text ("No boards yet")
    - Add backend/generate target for templ + go generate
    - Use go run for templ (no global install needed)
    - Simplify CI workflow: make targets handle all dependencies
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2026-03-29 fix: firmware connectivity — update server URL, fix memory issues, stabilize boot
    - Point DEFAULT_SERVER_URL to device.pcb.nyc and hardware ID to nyc-subway/v1
    - Add TLS cert bundle (crt_bundle_attach) to state_client HTTP config
    - Heap-allocate protobuf decode structs (DeviceState ~15KB, DeviceBoard ~6KB,
    DeviceScript ~17KB) — stack-allocating these crashed the 12KB state_task
    - Reduce Lua VM memory cap from 80KB to 32KB; remove 19KB of duplicated
    board/station_leds snapshot buffers from render task
    - Defer LED driver and OTA init until after WiFi connects to avoid SPI bus
    conflicts with WiFi radio init (phy_init)
    - Move WiFi got-IP work off wifi_manager's 4KB callback stack into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
    [main.py]
2026-03-29 fix: firmware stability, LED output, Lua script reload, brightness control
    - Fix protobuf decode failure: config array too small (50→80) for 64 entries
    - Fix Lua allocator unsigned underflow causing OOM on script reload
    - Fix heap leak: persistent HTTP client with keep-alive, reuse protobuf buffers
    - Fix LED driver: add per-strip SPI refresh diagnostics via server query string
    - Recreate Lua VM from scratch on script change (clean memory state)
    - Run Lua GC before render() for maximum free memory during execution
    - Move LED init before WiFi, clear strips to reduce power draw during radio cal
    - Add diagnostic query params to device-state requests for remote debugging
    Service:
    - A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
2026-03-29 fix: board fetch crash, race condition, remote diagnostics
    - Fix race condition: render task read board strip_count/strip_sizes
    without mutex while state_task wrote them — snapshot under mutex now
    - Fix fetch_board crash by rewriting with step-by-step error tracking
    - Fix memory leaks in fetch_board/fetch_script error paths
    - Add detailed remote diagnostics: fetch errors, Lua errors, reload
    status, heap stats, and first-lit-LED position in device-state query
    - Increase Lua instruction limit 100K→500K (snake script exceeded it)
    - Increase state_task stack to 16KB for TLS headroom
    - Revert to per-request HTTP client (persistent client caused crashes)
    - Remove health ping (diagnostics n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
2026-03-30 fix: disable Lua instruction limit, pause SPI during HTTP, add reset reason diag
    - Disable Lua instruction hook (was causing script_exceeded_instruction_limit
    errors — snake/track scripts legitimately need >500K instructions per frame)
    - Pause LED SPI refresh during HTTP fetches to reduce peak current draw
    (concurrent TLS handshake + SPI DMA causes brownout/power-on resets)
    - Add esp_reset_reason() to diagnostic query string for remote crash analysis
    - Fix diag error priority: show Lua errors over fetch success markers
2026-03-30 fix: cap WiFi TX power to 10dBm, fix Lua float-to-int errors in set_led
    WiFi PHY calibration at default 20dBm exceeded the AP2127K-3.3 LDO's
    300mA limit, causing hard resets (POWERON_RESET) on every boot.
    Capping TX power to 10dBm keeps current within budget.
    Both snake.lua and track.lua passed float values to set_led() when
    brightness scaling produced non-integer results. Lua 5.4's
    luaL_checkinteger rejects these. Wrap in math.floor().
2026-03-30 fix: scope E2E delete-plugin test to its own plugin ID
    Parallel workers share the same database, so waitForResponse on any
    DELETE /api/v1/plugins/ could catch another worker's request. Capture
    the plugin ID from the POST response and filter the DELETE response
    matcher to that specific ID.
2026-03-30 refactor: firmware logging, diagnostics API, HTTP abstraction, board config
    - Add device_log module with ring buffer for remote log collection
    (toggled via server config key "remote_log=1")
    - Replace URL query string diagnostics with structured DeviceDiagnostics
    protobuf sent as POST body on /api/v1/device-state
    - Extract http_client module from state_client (GET/POST, shared headers)
    - Add board_config for runtime hardware config with NVS override support
    - Extract device_diag_t struct, move globals into render_context_t
    - Pass render_context to led_driver for diagnostics
    - Delete dead code: subway_client, boot_animation, unused stubs
    - Server: parse diagnostics, store in new DB table,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
2026-03-30 fix: Docker CSS build, E2E delete test, site/build generation
    Dockerfile: copy generated _templ.go files from builder into frontend
    stage so Tailwind can scan all class names during CSS build. Fixes
    missing color swatch and slider styles in production.
    E2E: target delete button within [data-selected="true"] sidebar entry
    instead of first delete button, preventing wrong-plugin deletion when
    multiple plugins exist from prior scenarios.
    Makefile: add backend/generate dependency to site/build so templ + go
    generate run before generate-site, fixing undefined ui.Landing on CI.
2026-03-30 revert: remove unnecessary COPY --from=builder in Dockerfile
    Tailwind scans .templ source files directly via @source glob — no need
    to copy generated _templ.go files into the frontend stage.
2026-03-30 fix: stack overflow + station array overflow causing overnight freeze
    - Move DeviceDiagnostics (2.3KB) off stack to static (was overflowing 16KB task stack during TLS)
    - Bump stations max_count 200->300 (MTA sends 275 during peak hours, causing decode failure)
    - Reduce DeviceScript.config max_count 80->60 (firmware doesn't use script config, saves heap)
    - Add nanopb decode error string to log output
2026-03-30 fix: mobile horizontal overflow, landing page missing hashed assets
    Board page: add overflow-hidden to the 800px ambient glow container
    so it doesn't push the body wider than the viewport on mobile.
    generate-site: load Vite manifest before rendering so the static
    landing page references hashed asset filenames (main-abc123.css).
2026-03-30 test: add page integrity E2E tests for overflow and broken assets
    New page-integrity.feature checks every page (/boards, /community,
    /editor, /landing) at both desktop and mobile viewports for:
    - No horizontal overflow (scrollWidth <= innerWidth)
    - All local CSS/JS assets return HTTP 200
    Enable --dev flag on E2E server so /landing route is available.
    Fix mobile delete-plugin test: use dispatchEvent to bypass viewport
    clipping on the sidebar's delete button.
2026-03-30 fix: move DeviceState decode buffer to BSS to prevent heap fragmentation
    calloc/free of 24KB every second caused heap fragmentation that
    crashed the device after ~5 hours. Static buffer uses BSS instead,
    trading RAM% (47.2% vs 40.1%) for zero heap churn.
2026-03-30 fix: harden firmware synchronization, error handling, and build consistency
    - Replace all portMAX_DELAY with 500ms mutex timeout + graceful recovery
    - Protect diag writes in lua_runtime with mutex (was a race condition)
    - Add HTTP response buffer overflow warning
    - Add configASSERT on mutex allocation
    - Add led_driver_map_pixel() to eliminate duplicated strip offset logic
    - Add HTTP retry with exponential backoff (3 attempts)
    - Validate strdup result before swapping lua_source pointer
    - Log SPI refresh failures with error name
    - Replace magic numbers with named constants (RENDER_INTERVAL_MS, MUTEX_TIMEOUT_MS)
    - Fix HeathResponse typo → HealthResponse
    - Log json.Encode/M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
2026-03-31 refactor: rewrite firmware from C to C++20
    Replace ~1,800 lines of C with structured C++20 modules:
    - core/: Rgb type, DoubleBuffer<T> (lock-free SPSC), ScriptChannel
    (drain-on-overwrite queue), extern "C" Lua header wrapper
    - config/: constexpr constants, BoardHwConfig with NVS overrides
    - data/: TransitSnapshot, BoardSnapshot + BoardStore (single buffer +
    mutex), DiagPad with atomic fields
    - log/: device_log with LogLevel enum class, ring buffer
    - proto/: codec namespace wrapping nanopb encode/decode
    - hal/: instance-based LedDriver with Rgb pixel buffer and std::span
    - net/: instance-based HttpClient, mutex-free StateClient publishing
    to DoubleBuffer
    - script/: registry-based LuaBi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
    [board_config.cpp]
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2026-03-31 style: add clang-format for firmware C++ and auto-format all sources
    Add .clang-format config matching existing code style (4-space indent,
    attached braces, 100-col limit, C++20). Format check integrated into
    lint/firmware Makefile target and CI. Add fmt/firmware for auto-fix.
    Format check is skipped locally if clang-format is not installed.
    [board_config.cpp]
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2026-04-01 test: add E2E pipeline tests, unify fixtures and test utils
    Add end-to-end tests that validate the full data pipeline:
    protobuf encode → codec decode → BoardSnapshot → Lua render → pixels.
    Loads production track.lua from service/internal/lua/ instead of inline.
    - test_fixtures.hpp: shared fixtures for conformance + E2E tests
    - test_utils.hpp: shared Lua VM creation, check(), file reading
    - Vendor nanopb sources for host build (replaces stub pb.h)
    - .gitignore: add firmware/test/e2e binary
    [test_fixtures.hpp]
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2026-04-01 fix: make LedDriver::refresh_strip_spi const (cppcheck finding)
    [led_driver.cpp]
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2026-04-01 ci: add Trunk Check for unified multi-language linting
    Replace individual lint CI steps with trunk-io/trunk-action for Go,
    TypeScript (Biome), Python (ruff), and YAML. Firmware build + cppcheck
    + clang-format stays as make lint/firmware (needs PlatformIO).
    - trunk check runs all linters with unified pretty output and caching
    - Hold-the-line: PRs only flag newly introduced issues
    - Pre-commit hook uses trunk check for speed
    - CI adds dedicated Lint job via trunk-action
    [.isort.cfg]
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2026-04-02 feat: USB serial interface, collapsible board panels, and vite/NVS fixes
    - Add serial protocol handler for ESP32 (firmware) with command parsing,
    WiFi config, firmware flash, diagnostics, factory reset, and script upload
    - Add Web Serial frontend: SerialProtocol, device/wifi/flash/script modules,
    Alpine panels for WiFi config, firmware OTA, diagnostics, and device actions
    - Fix NVS type mismatch: serial handler now writes WiFi credentials as blobs
    (matching wifi_manager format) instead of strings
    - Merge Diagnostics and Device Actions into a single collapsible Advanced panel
    - Make all board settings panels collapsible with chevron toggle
    - Always show WiFi network dropdown (disabled w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
    [main.cpp, serial_handler.cpp]
